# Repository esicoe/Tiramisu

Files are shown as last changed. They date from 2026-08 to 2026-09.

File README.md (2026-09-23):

# Tiramisu: a 1000 Hz Hall-effect osu! tablet

<p align="center">
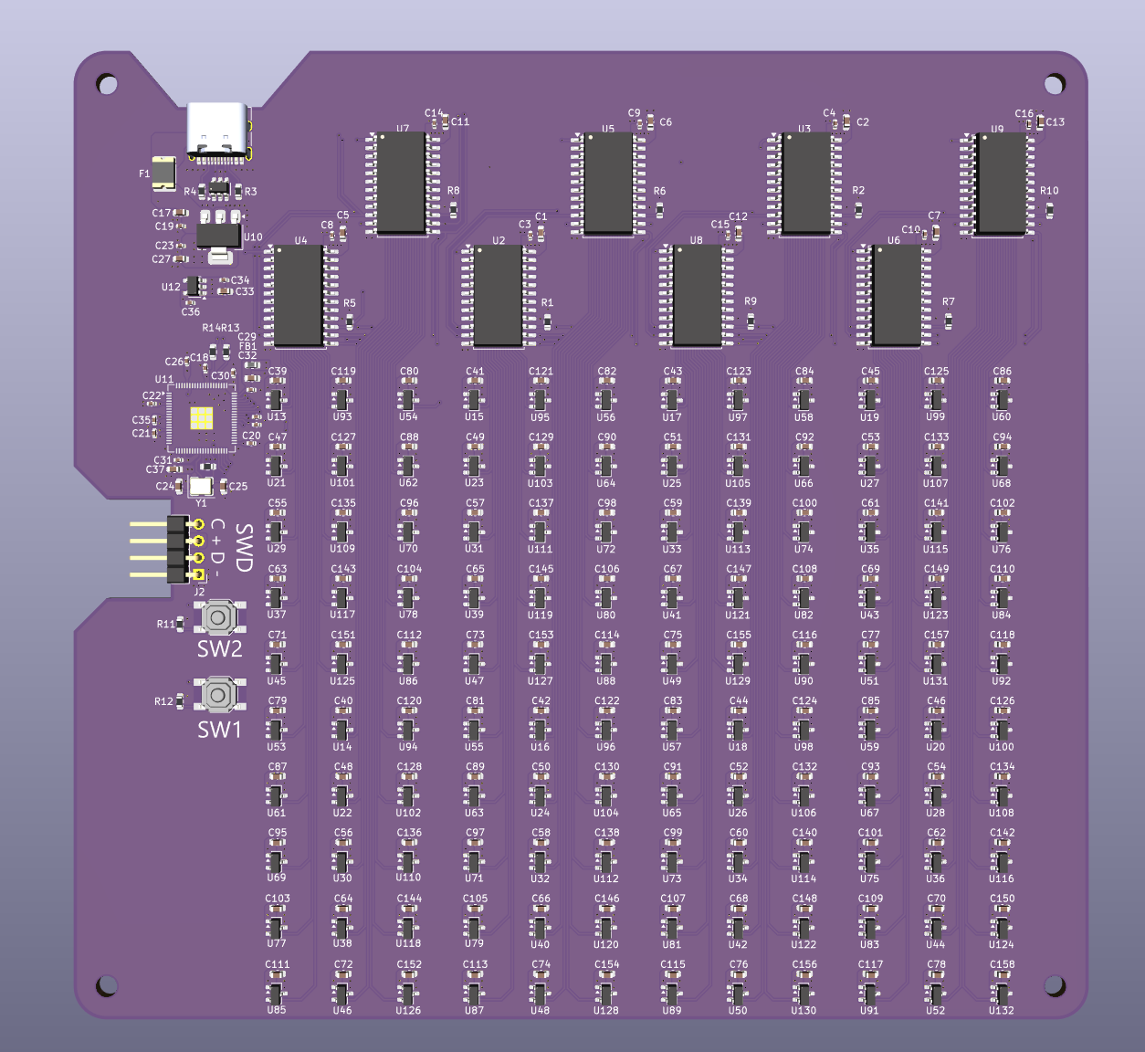
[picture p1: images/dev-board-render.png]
KiCad render of the aim1k dev board
  
</p>

Tiramisu is a drawing tablet for [osu!](https://osu.ppy.sh) that tracks a magnet-tipped pen with a grid of
120 Hall-effect sensors and reports its position over USB **1000 times a second**. That's the USB Full-Speed
ceiling, and 7.5x the 133 Hz of a Wacom CTL-472.

It's my independent prototype of the Hall-effect tablet we're building at
[Wonkle](https://github.com/wonkleio). The board and firmware go by **aim1k** in the source.

## Status

| Board | State |
|---|---|
| `tiramisu-dev-RP2354B` | Fabricated and assembled by JLCPCB, brought up, tracking a magnetic pen |
| `tiramisu-dev-CH32V307` | Next revision, in part selection: a RISC-V MCU with built-in USB 2.0 High-Speed to go past 1 kHz |

## Hardware: `tiramisu-dev-RP2354B`

| | |
|---|---|
| MCU | Raspberry Pi RP2354B (dual Arm Cortex-M33, 2 MB in-package flash) |
| Sensors | 120 x HAL403 linear Hall sensors in a 12 x 10 grid at 10 mm pitch |
| Multiplexing | 8 x CD74HC4067 16:1 analog muxes on a shared select bus, one per ADC input |
| PCB | 4 layers, 154 x 147 mm, designed in KiCad |
| Interface | USB-C (Full-Speed): HID plus an optional CDC debug console. SWD header for debugging |

## How it works

- **Scan (core 1).** DMA-driven round-robin over all 120 sensors at about 1.8 kHz per full frame, keeping a
  baseline and a noise sigma for every sensor. A warm-up conversion pass removes the crosstalk that the
  multiplexers' on-resistance causes in the ADC's sample-and-hold.
- **Solve (core 0).** Detects the pen from per-sensor noise thresholds and spatial coherence, seeds a position
  from the centroid, then refines x, y and hover height with a Levenberg-Marquardt fit of a magnetic dipole. A
  1-Euro filter smooths the output without adding lag during fast flicks.
- **Report.** 1 kHz USB HID, paced by the host's polling. The device exposes two collections: an absolute mouse
  that works with no driver, and a vendor-defined collection for [OpenTabletDriver](https://opentabletdriver.net).

The [firmware README](tiramisu-dev-RP2354B/firmware/README.md) covers the solver, the tuning decisions and how
to test without hardware. The [sensing calculations](tiramisu-dev-RP2354B/docs/CALCULATIONS.md) cover grid
geometry, scan-rate budget and magnet choice.

## Repository layout

```
tiramisu-dev-RP2354B/
  pcb/               KiCad project: schematic and 4-layer layout
  manufacturing/     Gerbers, BOM and pick-and-place files for JLCPCB
  firmware/          C firmware on the Pico SDK and TinyUSB
  scripts/           Python host tools
  opentabletdriver/  OpenTabletDriver tablet config and report parser
  docs/              Sensing and scan-rate calculations
  datasheets/
tiramisu-dev-CH32V307/   Next revision (datasheets so far)
images/                  Photos and renders for this README
```

## Build and flash

The build uses the Raspberry Pi Pico SDK. The Pico VS Code extension installs the SDK, the Arm toolchain, CMake
and Ninja in one go.

```powershell
cd tiramisu-dev-RP2354B/firmware
.\build.ps1           # configure (first time) and build
.\build.ps1 -Clean    # wipe build/ and reconfigure
```

Hold **BOOTSEL**, plug the board in, and copy `build/aim1k.uf2` onto the drive that appears.

## Host tools

All of these are Python 3 with no third-party packages. The USB tools use Windows APIs.

| Script | What it does |
|---|---|
| `scripts/grid_view.py` | Live heatmap of the sensor grid over the debug console, plus noise, raw, baseline and recalibrate views |
| `scripts/rate_test.py` | Measures the real HID report rate and its jitter at the host |
| `scripts/set_mode.py` | Turns the driverless mouse collection on or off |
| `scripts/gen_sensor_map.py` | Regenerates the firmware's sensor map straight from the KiCad PCB |

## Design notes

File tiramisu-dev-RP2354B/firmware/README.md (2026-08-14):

# aim1k tablet firmware

RP2354B firmware that scans the 120-sensor HAL403 grid, localises the pen magnet,
and reports absolute position over USB through two HID collections — an absolute
mouse (driverless cursor, no Windows Ink) and a vendor-defined one for
OpenTabletDriver. Deliberately NOT a Digitizer/Pen device; see config.h for why.

## Layout

```
include/config.h        build-time config (USB IDs, area, rates, DSP knobs)
include/sensor_map.h    AUTO-GENERATED (mux/channel -> grid) from the KiCad PCB
include/hid_report.h    the 7-byte pen report struct
src/sensors.[ch]        core-1 DMA round-robin scan -> 120 deflections (seqlock),
                        per-sensor baseline + noise sigma (Welford)
src/solve.[ch]          presence (sigma + spatial coherence + hysteresis) and
                        localisation (centroid seed -> LM dipole fit)
src/filter.[ch]         1-Euro adaptive output filter
src/usb_descriptors.c   mouse + vendor collections, optional CDC console,
                        TinyUSB glue
src/tusb_config.h       TinyUSB config
src/main.c              core-0: USB + solve + filter + 1 kHz report loop
../scripts/grid_view.py host-side live heatmap over the CDC console
```

## Debug console

`DEBUG_CONSOLE 1` (default) adds a USB CDC serial port alongside the HID
interface. It is how the sensor map and the noise thresholds get verified:

```bash
python ../scripts/grid_view.py        # live heatmap
```

Touch the magnet to one physical sensor and confirm the lit cell appears at the
matching (col,row). If it lights elsewhere, that entry in `SENSOR_GRID` is wrong
and the heatmap shows where it actually landed. `noise`, `raw`, `baseline`, and
`cal` are the other subcommands. Set `DEBUG_CONSOLE 0` for a release build to
drop the CDC interface entirely.

Over a raw serial terminal the console also takes single keys — `i` for a status
line and `j` for a jitter measurement:

```
i    scan 1812 Hz | sigma min 0.75 mean 1.31 max 2.04 counts | solve 61 us avg 88 us max (budget 1000)
     pen IN  peak 197.4 snr 96.8 coh 0.11  x 59.51 y 40.02 z 10.3 (dipole) rms 1.9
```

The four numbers to read when something is wrong:

- **`solve ... us`** against the 1000 µs budget. The report loop runs at 1 kHz;
  if the average approaches that, the fit is not finishing in its slot.
- **`rms` against `peak`.** This is the dipole fit's residual — how well a real
  magnet is described by the model. It should be a few percent of `peak`. If it
  sits near `FIT_MAX_RESID_FRAC` (0.25) with the pen plainly on the tablet, the
  fit-quality gate is rejecting good frames and that constant needs raising.
- **`coh`.** Spatial coherence, which falls as the pen gets *closer* (see the
  table in `config.h`). Under `COHERENCE_MIN` the pen is not detected at all.
- **`z`.** Fitted hover height. Over `HOVER_MAX_Z_MM` the pen drops out.

`j` parks a 2-second capture and reports the standard deviation and
peak-to-peak of the reported position, before and after the output filter:

```
j    jitter over 2000 frames (mm)
       solver   sd 0.1103 0.1147  p2p 0.612 0.658
       filtered sd 0.0129 0.0134  p2p 0.083 0.094
```

Hold the pen still and read the **filtered p2p** — that is how far the cursor
wanders on its own. A large p2p next to a small sd means isolated glitches
rather than noise, which is the one case `MEDIAN_TAPS 3` is for.

## Build

```powershell
.\build.ps1            # configure (first time) + build
.\build.ps1 -Clean     # wipe build/ and reconfigure
```

`build.ps1` finds the toolchain in either place one ends up: a standalone
`C:\pico` layout, or `%USERPROFILE%\.pico-sdk\` — which is what the Raspberry Pi
Pico VS Code extension installs, and which brings its own SDK, arm-none-eabi,
CMake, Ninja and picotool. It picks the newest version of each.

Output is `build/aim1k.uf2`. To flash: hold **BOOTSEL**, plug in the RP2354B,
copy `aim1k.uf2` onto the drive that appears.

Current build: **46 KB flash, 15 KB RAM** — trivially fits the RP2354B's 2 MB /
520 KB. (Most of that is the SDK 2.3.0 / GCC 15 toolchain rather than this code;
the same source was 20.7 KB under SDK 2.1.1 / GCC 13.)

Building the firmware is not the only way to work on the solver — see *Testing
the solver without hardware* below.

## Why the cursor holds still

A 10 mm sensor pitch means the position between sensors is *interpolated*, so
every discrete decision the solver makes is a chance to turn a stationary magnet
into a moving cursor. Five things exist purely to stop that, in rough order of
how much they matter (all measured against synthetic frames — peak 200 counts,
sigma 2, magnet at 8 mm — with the harness described below):

1. **Priors on the fit's nuisance parameters** (`FIT_NUISANCE_PRIOR`). Magnet
   strength `A` and hover height `z` cannot change at 1 kHz, but the fit
   re-derived them every frame, and because the model's parameters are
   correlated their noise came back out as *position* noise. Tying them to the
   previous frame while leaving x/y completely free: 0.131 → 0.058 mm rms with
   `z` pinned outright, 0.111 mm with the adaptive prior actually shipped. No
   latency cost, because position is never constrained.
2. **Coherence threshold** (`COHERENCE_MIN`, 0.18 → **−0.10**). This one took two
   goes to get right, and the reason is worth stating plainly: **coherence is a
   monotonically decreasing function of how close the pen is**, because the
   peak's neighbours 10 mm away sit in the dipole's *negative skirt*. So any
   positive threshold is a minimum hover height in disguise — press the pen down
   harder and the tablet cuts out. At 0.18 the pen did not exist below ~10 mm.
   Lowering it to 0.05 moved the wall rather than removing it: a left-edge drag
   measured 100% usable at 7 mm, 99.8% at 6 mm, and **79% at 5 mm with presence
   chattering 213 times in four seconds** — every failure the coherence test,
   with amplitude, residual, height and area never firing. Only a negative floor
   removes the wall entirely. It now sits below what a magnet produces at ~3 mm,
   which is below anything a 10 mm pitch can localise anyway.
3. **Baseline time constant** (`BASELINE_ALPHA`, 0.0005 → 3.0e-5) and freezing
   it while a pen is present. At ~1.8 kHz the old value was a 1.1 *second* time
   constant sitting directly under the pen: rest the magnet anywhere and the
   baseline crawled up to meet it, eating the blob's skirt first and deforming
   the shape the solver was fitting.
4. **Peak-cell hysteresis** (`PEAK_HOLD_MARGIN_SIGMA`). The analysis window
   hangs off the argmax; a magnet parked between two sensors let noise re-decide
   that every frame, sliding the window a full pitch each time.
5. **Frame-count debounce** on presence, so a marginal frame costs nothing
   instead of a filter reset and a cursor jump.

End to end, worst position found by sweeping the magnet over a 10 × 10 mm cell
at 0.5 mm steps, cursor peak-to-peak with the output filter in place:

| hover | before | after |
|---|---|---|
| 8 mm  | 0.54 mm | 0.25 mm |
| 12 mm | 1.02 mm | 0.51 mm |

Latency is unchanged: 0.88 ms at 400 mm/s (was 0.87), 3.81 ms at 40 mm/s (was
4.13, i.e. slightly better).

## Out of range

`solve_position` reports `in_range` false — and `main.c` then stops sending
reports entirely, freeing the cursor — when any of these hold for
`PRESENCE_EXIT_FRAMES` consecutive frames:

- **the peak has collapsed to under `PRESENCE_RELEASE_FRAC` of what this contact
  has been reading.** This is the test that actually releases the pen, and it is
  relative because no absolute one can work: the threshold has to sit low enough
  for the weakest pen worth seeing, and a strong magnet reading 865 counts would
  have to travel nearly 4x further away before it fell through
  `PRESENCE_EXIT_SNR * sigma` ≈ 16 counts. The reference is a symmetric average
  over `PEAK_REF_TAU_S`, so any hover height held for longer than that simply
  becomes the new reference and only a change faster than it — lifting the pen —
  trips the test;
- peak below `PRESENCE_EXIT_SNR` sigma, or coherence below `COHERENCE_EXIT_MIN`
  (pen gone, or a single drifted sensor pretending to be one);
- fitted `z` over `HOVER_MAX_Z_MM` (pen held too high to localise);
- fit residual over the `FIT_MAX_RESID_*` gate (whatever is on the grid is not
  a magnet on the surface);
- the fit places the pen more than `AREA_MARGIN_MM` outside the sensor-centre
  span (**pen off the edge of the tablet**).

That last one is only possible because the fit's x/y are unconstrained: push the
magnet past the last column and the peak cell stays pinned to that column, but
the fit — which knows what the field's shape should look like — reports a
position out beyond the edge. A centroid cannot do this; it is trapped inside
the grid, which is why a centroid-only tablet smears and jitters along its
border instead of admitting the pen has left.

### The phantom pen

A phantom is a POSITIVE blob on the grid with no magnet present, and there is
exactly one way to make one: the baseline learned a value that is too LOW,
which means it was learned while a NEGATIVE field sat on the tablet. A negative
field is the magnet's other pole — the pen resting flipped, or lying on its
side, which is the natural way to put a pen down. Presence only searches for
positive peaks, so a negative field is invisible to it, and any ungated "no pen
detected, track freely" baseline rate will absorb it wholesale. Pick the pen up
and its positive mirror image stands up out of the corrected-for field: full
pen amplitude, dipole-shaped to within noise (it IS the pen's field, frozen),
fitting a plausible hover height. It passes every test the solver has, because
it is a perfect recording of something that passed every test. One was captured
on hardware holding peak ~900 / z 12.0, motionless, for five unbroken minutes.

Weak phantoms exist too (drift accumulated under a long-parked pen, the
positive ring around the hole left by calibrating with the magnet on), but the
full-amplitude image is the one that cannot be beaten after the fact: a real
pen between sensors reads LESS than the image does, so no amplitude contest,
threshold, or release rule can prefer the pen once the image exists. The only
winning move is to make images impossible to create. Defences, in order:

1. `BASELINE_GATE_SNR` — no baseline rate may follow a deflection beyond a few
   sigma, in either polarity. Drift creeps, so a tracking baseline never
   legitimately sees more; anything bigger is a field, and fields are never
   absorbed. This kills the formation path outright.
2. The post-release re-zero pass (`BASELINE_ALPHA_REZERO`) is the single
   exception, and it is ungated for POSITIVE deflections only — its targets
   (leftover images, drift from under a parked pen) are positive, and
   absorbing a large negative deflection is precisely the act of minting a
   phantom.
3. `PRESENCE_REACQUIRE_BLOCK_MS` — after a release, nothing may be acquired,
   flat, no exceptions, while the re-zero runs. An image is at full pen
   amplitude, so any exception lenient enough to admit a returning pen admits
   the image, which then freezes its own neighbourhood and cancels the erase.
4. The peak tracker never walks to a FAR rival while its own cell's signal has
   collapsed. One magnet cannot jump several pitches in a millisecond, so that
   situation is always "the pen left while a second source exists" — hold the
   dying cell, release, and let the re-zero deal with whatever the rival is.
   This is both how weak phantoms get erased by ordinary use (one contact and
   lift heals them) and why the cursor no longer teleports onto a second blob
   whenever the pen lifts.

What remains: a full image can still be BAKED IN by booting — the calibration
runs ~0.5 s after power-up and trusts whatever it sees — with a magnet resting
on (or flipped on) the tablet. Nothing at runtime can distinguish that from a
clean zero, so keep the tablet clear when plugging in; `c` on the console
re-zeros and fixes it immediately if it happens.

## Testing the solver without hardware

`solve.c` and `filter.c` have no SDK dependencies beyond `sensor_map.h`, so they
compile natively against a synthetic grid. The magnet is modelled as a pair of
magnetic charges (a finite cylinder), *not* as the point dipole the solver fits,
so the fit sees real model mismatch; per-sensor gain spread is included for the
same reason. Stub `sensors_sigma()` and friends, generate frames, and measure.
This is how every number above was obtained, and it is much faster than
guessing at a tablet.

## Bring-up order (do these on a scope/logic analyser first)

1. **Confirm HAL403SO is the linear/ratiometric part** (analog output). The ADC
   path is meaningless for a switch-type Hall. See `../datasheets/HAL403.pdf`.
2. **Select-line sanity.** Toggle S0..S3 (GPIO32/31/30/29) and verify each mux
   walks channels 0..14. `sensor_map.h` assumes address = channel index.
3. **Settle time.** `sensors.c: set_address()` waits 5 µs. Scope one COM line
   after an address change and shrink/grow this until it is just clean at 12-bit.
4. **Baseline + polarity.** With no pen, `sensors_calibrate_baseline()` should
   leave deflections near zero. Bring the magnet down over one sensor and confirm
   the deflection goes **positive** (the code weights on positive deflection). If
   it goes negative, flip the magnet, or negate in `raw_frame()`.
5. **Grid orientation.** Move the pen right/down and confirm reported X/Y move the
   right way. Add axis flips in `main.c: send_pen()` if the board is mounted
   rotated/mirrored.

## Known stubs / next steps

- **Clicks are keyboard-only, by design.** The tablet is hover-only: it reports
  position and never asserts a tip switch. Bind osu! K1/K2 on the keyboard as
  usual. Pressure stays 0.
- **DMA round-robin on core 1** is done: core 1 scans the grid (DMA drains the 8
  ADC inputs per address) and publishes frames through a seqlock; core 0 only
  runs USB + solve. Core-1 frame rate is ~1.4 kHz (2x oversampled), independent
  of the 1 kHz report loop, with headroom to push higher (drop OVERSAMPLE or
  trim the 5 us settle in `sensors.c`).
- **Dipole refine** in `solve.c` is implemented (Levenberg-Marquardt over the
  5x5 window, falling back to the centroid if it fails to converge or wanders
  outside the window). It removes the centroid's edge bias and its bias from the
  field's negative skirt.
- Regenerate `sensor_map.h` whenever the PCB changes:
  `python ../scripts/gen_sensor_map.py --write`. It reads placements, net
  connectivity, and pin functions out of `pcb/tiramisu-dev.kicad_pcb`, so it never
  assumes a pinout — which matters, because the CD74HC4067 footprint here does
  not use the pad order the datasheet would suggest (pad 1 is COM, not I5), and
  the ADC net names are reversed relative to the ADC input numbers.
- Confirm the map on hardware with `../scripts/grid_view.py` after regenerating.

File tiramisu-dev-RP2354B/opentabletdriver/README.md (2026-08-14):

# aim1k — OpenTabletDriver support

Two files:

- `aim1k.json` — the tablet configuration (VID/PID, physical size, report parser).
- `Aim1kReportParser.cs` — decodes the 8-byte HID report into an OTD report.

## Why both

The firmware exposes a **vendor-defined HID collection** alongside the
absolute-mouse one (see `HID personality` in `../firmware/include/config.h`).
That is deliberate, and it is what makes OTD work at all:

- Windows opens **Digitizer/Pen** collections **exclusively**. With a pen
  descriptor, OTD — or any other userspace reader — gets `ACCESS_DENIED` when it
  tries to open the device. No OTD config can work around that.
- A pen descriptor also puts **Windows Ink** in the path, which is exactly the
  smoothing and press-and-hold behaviour osu! players turn off.

A vendor-defined collection sidesteps both. On its own it would mean nothing
moves the cursor without OTD, which is why the firmware also ships the
absolute-mouse collection beside it: Windows claims collections individually, so
the mouse drives the cursor driverless while the vendor one stays open for OTD.
OTD switches the mouse off when it connects (`FeatureInitReport` below) so the
two never fight. Set `VENDOR_ONLY 1` in `config.h` to drop the mouse collection
entirely, or `MOUSE_DEFAULT_ON 0` to leave it silent until something asks.

## Install

**No plugin DLL is needed.** `Aim1kReportParser.cs` is kept only as a starting
point if you later want proximity or pressure handling; the stock parser covers
the current report exactly.

1. Copy `aim1k.json` into the OTD configurations folder:
   - Windows: `%LOCALAPPDATA%\OpenTabletDriver\Configurations\`

   Creating that folder is safe: OTD **adds** these to its built-in configs
   rather than replacing them (verified on 0.6.7 — 341 configs loaded, all the
   stock ones still present alongside aim1k).

2. **Restart the OTD daemon.** This step is not optional and is the most likely
   thing to waste your time: the daemon enumerates HID devices once at startup,
   so a daemon that was already running when you reflashed the firmware will
   report `Device not found` even though the config loads and the device is
   plainly visible to everything else. Kill `OpenTabletDriver.Daemon.exe` and
   start it again after any reflash that changes the USB descriptors.

3. The tablet appears as **"aim1k tablet"**, 110 × 90 mm. Map your osu! area
   inside that with output mode *Absolute*.

A healthy detection looks like this in the log
(`%LOCALAPPDATA%\OpenTabletDriver\Logs\`):

```
[Device] Initializing device 'aim1k tablet' \\?\hid#vid_1209&pid_0001&mi_02&col02#...
[Device] Using report parser type 'OpenTabletDriver.Plugin.Tablet.TabletReportParser'
[Device] Set device feature: 03-00
[Detect] Found tablet 'aim1k tablet'
```

`col02` confirms it bound to the vendor collection rather than the mouse one, and
`Set device feature: 03-00` is `FeatureInitReport` switching the absolute-mouse
collection off so OTD alone drives the cursor.

## Notes

- `MaxX/Width = 100`, i.e. coordinates are in 0.01 mm — matches the firmware.
- Pressure is currently synthesised from the tip-switch bit (0 or full scale), so
  OTD's pressure-based tip binding works once you wire a tip switch. Until then
  the tablet is hover-only; bind clicks to the keyboard as usual for osu!.
- If OTD does not pick it up, double-check the VID/PID in `aim1k.json` matches
  `USB_VID`/`USB_PID` in `../firmware/include/config.h`.

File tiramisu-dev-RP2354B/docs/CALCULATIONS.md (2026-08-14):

# aim1k tablet — sensing calculations

All numbers below are derived from the KiCad files in `pcb/`
(120 × HAL403SO, RP2354B, 8 × CD74HC4067). Re-run the extraction in
`scripts/gen_sensor_map.py` if the board changes.

## 1. Grid geometry (measured from the PCB)

| Quantity | Value |
|---|---|
| Sensors | **120** (HAL403SO, SOT-23) |
| Layout | **12 columns × 10 rows** |
| Pitch | **10.0 mm** in X and Y |
| Sensor-centre span | **110 mm × 90 mm** (col 0→11, row 0→9) |
| Aspect ratio | 110:90 = 1.22 (osu! playfield is 4:3 = 1.33 — crop in software) |

**Usable active area.** A magnet is localised by interpolating between the
sensors that surround it. Near the outer edge the magnet is only "seen" from one
side, so accuracy degrades within ~½ pitch of the border. Plan for a reliable
interior of about **100 mm × 80 mm**, and let OpenTabletDriver map a smaller
osu! area inside that.

## 2. Electrical / scan architecture (from the schematic)

- **Select lines S0–S3 are a shared bus** → `S0=GPIO32, S1=GPIO31, S2=GPIO30, S3=GPIO29`.
- **Mux enables (E) are tied low in hardware** (10 kΩ to GND, not on the MCU),
  so **all 8 muxes are always enabled** and present their selected channel
  simultaneously.
- **8 mux COM outputs → the RP2350 ADC pins**, but the net names are **reversed**:
  net `ADC0` (mux A) is on **GPIO47 = ADC input 7**, … net `ADC7` (mux H) is on
  **GPIO40 = ADC input 0**. Encoded as `MUX_ADC_INPUT[A..H] = {7,6,5,4,3,2,1,0}`.
- **Each mux drives 15 sensors** (channels 0–14); **channel 15 is unused** on all
  eight. So a full frame is **15 select addresses × 8 muxes = 120 reads**.

The RP2350 has **one** ADC behind an 8-input front mux, so the 8 mux COMs are read
*round-robin*, not truly in parallel.

## 3. Scan-rate budget

Per select address: set 4 GPIOs, wait for the analog line to settle, then convert
8 channels round-robin.

| Item | Time |
|---|---|
| RP2350 ADC conversion | ~2.0 µs / sample (500 kSa/s) |
| 8 channels / address | ~16 µs |
| Mux + line settle (conservative) | ~5 µs |
| **Per address** | **~21 µs** |
| **15 addresses = full 120-sensor frame** | **~315 µs → ~3.2 kHz** |

Even at a pessimistic 2× overhead you clear **1.5 kHz full-grid**, so:

- **1000 Hz USB report rate is comfortably met** (USB Full-Speed, 1 ms interval).
- There is headroom to **oversample** (average 2–3 frames) to cut noise ~1.4–1.7×
  and still report at 1 kHz.
- Free-run the scan on **core 1** (DMA-fed round-robin), solve position on **core 0**.

## 4. Magnet & working height (this changes your earlier plan)

Pen magnet: **6 mm ⌀ × 10 mm** axially-magnetised NdFeB cylinder (N42≈Br 1.32 T).
On-axis field of a cylinder at distance `z` from the pole face:

```
B(z) = (Br/2) · [ (L+z)/√(R²+(L+z)²) − z/√(R²+z²) ],   R=3 mm, L=10 mm
```

| z (magnet face → sensor plane) | B |
|---|---|
| 5 mm | ~81 mT |
| 8 mm | ~33 mT |
| **10 mm** | **~21 mT** |
| 12 mm | ~14 mT |
| 15 mm | ~8 mT |
| 17 mm | ~6 mT |

**Key correction.** Earlier I said "get the magnet as close to the tip as
possible." That is right for a *single* sensor, but **wrong for a 10 mm-pitch
array.** If the magnet is 2–3 mm away the field is a sharp spike over essentially
one sensor and you **cannot interpolate** where between sensors it sits. For an
array the field "spot" at the sensor plane should span ~2–3 pitches, i.e. the
**working height should be ≈ the pitch, ~8–12 mm.**

So the target is:

```
working height  =  (tip-to-magnet-face gap)  +  (cover thickness)  ≈  8–12 mm
```

With a ~1.5–2 mm cover sheet, the **magnet face should sit ~6–10 mm behind the
pen-tip contact point** — not 2–5 mm, and not 15 mm.

- **Your current 15 mm** puts the magnet ~17 mm from the sensors → only ~6 mT and
  a broad, low-amplitude peak. Workable but noise-limited; pull it forward.
- **Sweet spot ≈ 8 mm behind the tip** → ~10 mm working height, ~21 mT, peak
  spread across a 3×3 neighbourhood. That is the number to build to.

## 5. Expected resolution

- Raw pitch is 10 mm, but with weighted-centroid / dipole interpolation over a
  3×3–5×5 neighbourhood and a 12-bit ADC, position resolution of **~0.05–0.2 mm**
  is realistic when SNR is good (another reason to favour ~21 mT over ~6 mT).
- Mapped to a 1920 px width over a ~100 mm area (~0.05 mm/px), that is roughly
  one-screen-pixel precision — adequate for osu!, **noise-limited, not
  pitch-limited**, which is why working height and calibration matter most.

## 6. Open hardware questions to confirm

1. **Is HAL403SO the linear/ratiometric Hall (analog output), not a switch?**
   The ADC readout only works with an analog-output part. Confirm against
   `datasheets/HAL403.pdf`.
2. **Pen click / tip switch.** A rigid magnet-in-pen gives *hover only*. osu!
   players usually click with the keyboard, so hover + keyboard is fine, but if
   you want a pen "tap = click" you need either a tip micro-switch (add a GPIO) or
   a z-threshold gesture. The firmware exposes a `tip_switch` bit that is
   currently stubbed off — wire it to whichever you choose.

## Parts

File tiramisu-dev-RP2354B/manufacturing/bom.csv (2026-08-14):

Designator | Footprint | Quantity | Value | LCSC Part #
C1, C11, C12, C13, C2, C33, C5, C6, C7 | 0603 | 9 | 1u | C15849
C10, C14, C15, C16, C18, C19, C20, C21, C22, C23, C26, C28, C3, C30, C31, C32, C34, C35, C36, C38, C4, C8, C9 | 0402 | 23 | 100n | C1525
C100, C101, C102, C103, C104, C105, C106, C107, C108, C109, C110, C111, C112, C113, C114, C115, C116, C117, C118, C119, C120, C121, C122, C123, C124, C125, C126, C127, C128, C129, C130, C131, C132, C133, C134, C135, C136, C137, C138, C139, C140, C141, C142, C143, C144, C145, C146, C147, C148, C149, C150, C151, C152, C153, C154, C155, C156, C157, C158, C39, C40, C41, C42, C43, C44, C45, C46, C47, C48, C49, C50, C51, C52, C53, C54, C55, C56, C57, C58, C59, C60, C61, C62, C63, C64, C65, C66, C67, C68, C69, C70, C71, C72, C73, C74, C75, C76, C77, C78, C79, C80, C81, C82, C83, C84, C85, C86, C87, C88, C89, C90, C91, C92, C93, C94, C95, C96, C97, C98, C99 | 0603 | 120 | 0.1u | C14663
C17 | 0603 | 1 | 10u | C96446
C24, C25 | 0603 | 2 | 15p | C1644
C27 | 0603 | 1 | 22u | C59461
C29, C37 | 0603 | 2 | 4u7 | C19666
F1 | 1812 | 1 | SMD1812P075TF/24 | C12557
FB1 | 0603 | 1 | GZ1608D601TF | C1002
J1 | USB_C_Receptacle_HRO_TYPE-C-31-M-12 | 1 | TYPE-C-31-M-12 | C165948
R1, R10, R2, R5, R6, R7, R8, R9 | 0603 | 8 | 10K | C25804
R11, R12, R15 | 0603 | 3 | 1K | C21190
R13, R14 | 0603 | 2 | 27R | C25190
R3, R4 | 0603 | 2 | 5.1K | C23186
SW1, SW2 | SW_SPST_SKQG_WithStem | 2 | TS-1187A-B-A-B | C318884
U1 | SOT-23-6 | 1 | SRV05-4 | C85364
U10 | SOT-223-3_TabPin2 | 1 | AMS1117-3.3 | C6186
U100, U101, U102, U103, U104, U105, U106, U107, U108, U109, U110, U111, U112, U113, U114, U115, U116, U117, U118, U119, U120, U121, U122, U123, U124, U125, U126, U127, U128, U129, U13, U130, U131, U132, U14, U15, U16, U17, U18, U19, U20, U21, U22, U23, U24, U25, U26, U27, U28, U29, U30, U31, U32, U33, U34, U35, U36, U37, U38, U39, U40, U41, U42, U43, U44, U45, U46, U47, U48, U49, U50, U51, U52, U53, U54, U55, U56, U57, U58, U59, U60, U61, U62, U63, U64, U65, U66, U67, U68, U69, U70, U71, U72, U73, U74, U75, U76, U77, U78, U79, U80, U81, U82, U83, U84, U85, U86, U87, U88, U89, U90, U91, U92, U93, U94, U95, U96, U97, U98, U99 | SOT-23 | 120 | HAL403SO | C42387470
U11 | QFN-80-1EP_10x10mm_P0.4mm_EP3.4x3.4mm | 1 | RP2354B | C39843328
U12 | SOT-23-5 | 1 | TLV73311PDBV | C2865431
U2, U3, U4, U5, U6, U7, U8, U9 | SOIC-24W_7.5x15.4mm_P1.27mm | 8 | CD74HC4067M | C496123
Y1 | Crystal_SMD_3225-4Pin_3.2x2.5mm | 1 | ABM8-272-T3 | C20625731

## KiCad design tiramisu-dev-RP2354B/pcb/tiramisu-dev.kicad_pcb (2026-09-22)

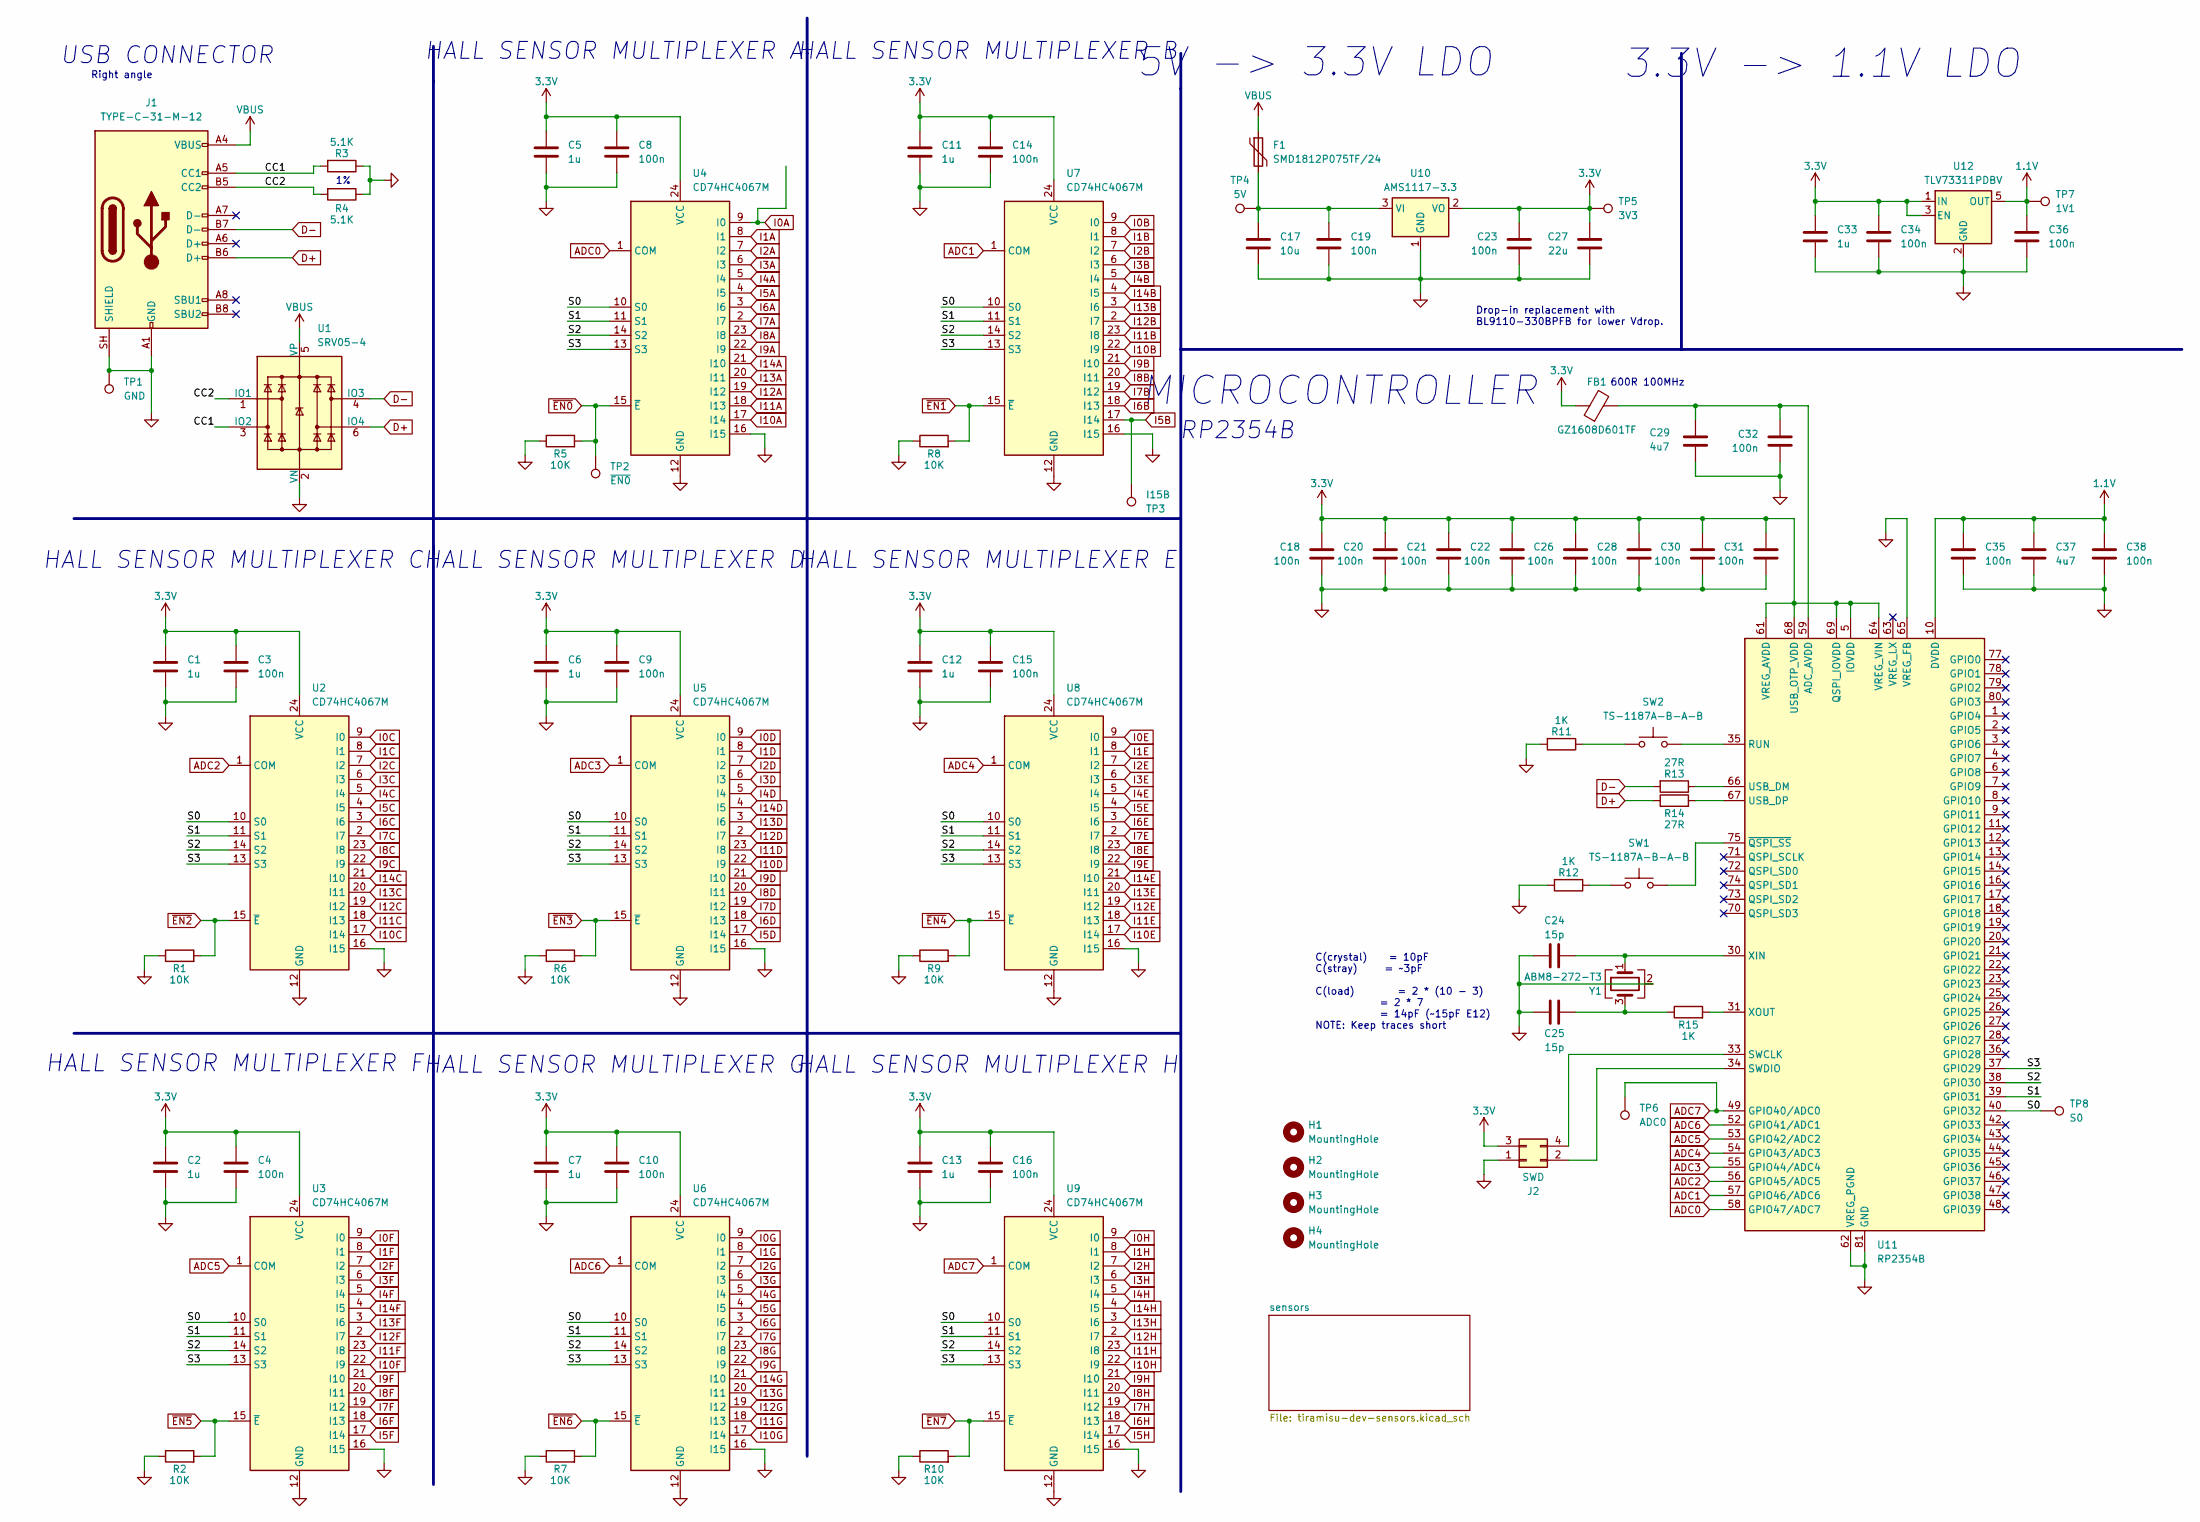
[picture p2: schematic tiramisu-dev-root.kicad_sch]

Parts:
C1, C2, C5, C6, C7, C11, C12, C13, C33: 1u; C_0603_1608Metric
C3, C4, C8, C9, C10, C14, C15, C16, C18, C19, C20, C21, C22, C23, C26, C28, C30, C31, C32, C34, C35, C36, C38: 100n; C_0402_1005Metric
C17: 10u; C_0603_1608Metric
C24, C25: 15p; C_0603_1608Metric
C27: 22u; C_0603_1608Metric
C29, C37: 4u7; C_0603_1608Metric
F1: SMD1812P075TF/24; Fuse_1812_4532Metric
FB1: GZ1608D601TF; L_0603_1608Metric
H1, H2, H3, H4: MountingHole; MountingHole_3.2mm_M3
J1: TYPE-C-31-M-12; USB_C_Receptacle_HRO_TYPE-C-31-M-12
J2: SWD; PinHeader_1x04_P2.54mm_Horizontal
R1, R2, R5, R6, R7, R8, R9, R10: 10K; R_0603_1608Metric
R3, R4: 5.1K; R_0603_1608Metric
R11, R12, R15: 1K; R_0603_1608Metric
R13, R14: 27R; R_0603_1608Metric
SW1, SW2: TS-1187A-B-A-B; SW_SPST_SKQG_WithStem
TP1: GND; TestPoint_Pad_D4.0mm
TP2: ~{EN0}; TestPoint_Pad_D4.0mm
TP3: I15B; TestPoint_Pad_D4.0mm
TP4: 5V; TestPoint_Pad_D4.0mm
TP5: 3V3; TestPoint_Pad_D4.0mm
TP6: ADC0; TestPoint_Pad_D4.0mm
TP7: 1V1; TestPoint_Pad_D4.0mm
TP8: S0; TestPoint_Pad_D4.0mm
U1: SRV05-4; SOT-23-6
U2, U3, U4, U5, U6, U7, U8, U9: CD74HC4067M; SOIC-24W_7.5x15.4mm_P1.27mm
U10: AMS1117-3.3; SOT-223-3_TabPin2
U11: RP2354B; QFN-80-1EP_10x10mm_P0.4mm_EP3.4x3.4mm
U12: TLV73311PDBV; SOT-23-5
Y1: ABM8-272-T3; Crystal_SMD_3225-4Pin_3.2x2.5mm

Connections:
1.1V: C35.1, C36.1, C37.1, C38.1, TP7.1 (1_1), U11.10 (DVDD), U11.32 (DVDD), U11.51 (DVDD), U12.5 (OUT)
3.3V: C1.1, C2.1, C3.1, C4.1, C5.1, C6.1, C7.1, C8.1, C9.1, C10.1, C11.1, C12.1, C13.1, C14.1, C15.1, C16.1, C18.1, C20.1, C21.1, C22.1, C23.1, C26.1, C27.1, C28.1, C30.1, C31.1, C33.1, C34.1, FB1.1, J2.3, TP5.1 (1_1), U2.24 (VCC), U3.24 (VCC), U4.24 (VCC), U5.24 (VCC), U6.24 (VCC), U7.24 (VCC), U8.24 (VCC), U9.24 (VCC), U10.2 (VO), U11.5 (IOVDD), U11.15 (IOVDD), U11.24 (IOVDD), U11.29 (IOVDD), U11.41 (IOVDD), U11.50 (IOVDD), U11.60 (IOVDD), U11.61 (VREG_AVDD), U11.64 (VREG_VIN), U11.68 (USB_OTP_VDD), U11.69 (QSPI_IOVDD), U11.76 (IOVDD), U12.1 (IN), U12.3 (EN); also elsewhere on the board
/CC1: J1.A5 (CC1), R3.2, U1.3 (IO2)
/CC2: J1.B5 (CC2), R4.2, U1.1 (IO1)
/S0: TP8.1 (1_1), U2.10 (S0), U3.10 (S0), U4.10 (S0), U5.10 (S0), U6.10 (S0), U7.10 (S0), U8.10 (S0), U9.10 (S0), U11.40 (GPIO32)
/S1: U2.11 (S1), U3.11 (S1), U4.11 (S1), U5.11 (S1), U6.11 (S1), U7.11 (S1), U8.11 (S1), U9.11 (S1), U11.39 (GPIO31)
/S2: U2.14 (S2), U3.14 (S2), U4.14 (S2), U5.14 (S2), U6.14 (S2), U7.14 (S2), U8.14 (S2), U9.14 (S2), U11.38 (GPIO30)
/S3: U2.13 (S3), U3.13 (S3), U4.13 (S3), U5.13 (S3), U6.13 (S3), U7.13 (S3), U8.13 (S3), U9.13 (S3), U11.37 (GPIO29)
ADC0: U4.1 (COM), U11.58 (GPIO47/ADC7)
ADC1: U7.1 (COM), U11.57 (GPIO46/ADC6)
ADC2: U2.1 (COM), U11.56 (GPIO45/ADC5)
ADC3: U5.1 (COM), U11.55 (GPIO44/ADC4)
ADC4: U8.1 (COM), U11.54 (GPIO43/ADC3)
ADC5: U3.1 (COM), U11.53 (GPIO42/ADC2)
ADC6: U6.1 (COM), U11.52 (GPIO41/ADC1)
ADC7: TP6.1 (1_1), U9.1 (COM), U11.49 (GPIO40/ADC0)
D+: J1.B6 (D+), R14.1, U1.6 (IO4)
D-: J1.B7 (D-), R13.2, U1.4 (IO3)
GND: C1.2, C2.2, C3.2, C4.2, C5.2, C6.2, C7.2, C8.2, C9.2, C10.2, C11.2, C12.2, C13.2, C14.2, C15.2, C16.2, C17.2, C18.2, C19.2, C20.2, C21.2, C22.2, C23.2, C24.1, C25.2, C26.2, C27.2, C28.2, C29.2, C30.2, C31.2, C32.2, C33.2, C34.2, C35.2, C36.2, C37.2, C38.2, J1.A1 (GND), J1.A12 (GND), J1.B1 (GND), J1.B12 (GND), J1.SH (SHIELD), J2.1, R1.1, R2.1, R3.1, R4.1, R5.1, R6.1, R7.1, R8.1, R9.1, R10.1, R11.2, R12.2, TP1.1 (1_1), U1.2 (VN), U2.12 (GND), U2.16 (I15), U3.12 (GND), U3.16 (I15), U4.12 (GND), U4.16 (I15), U5.12 (GND), U5.16 (I15), U6.12 (GND), U6.16 (I15), U7.12 (GND), U7.16 (I15), U8.12 (GND), U8.16 (I15), U9.12 (GND), U9.16 (I15), U10.1 (GND), U11.62 (VREG_PGND), U11.65 (VREG_FB), U11.81 (GND), U12.2 (GND), Y1.2 (G), Y1.4 (G); also elsewhere on the board
I0A: U4.9 (I0); also elsewhere on the board
I0B: U7.9 (I0); also elsewhere on the board
I0C: U2.9 (I0); also elsewhere on the board
I0D: U5.9 (I0); also elsewhere on the board
I0E: U8.9 (I0); also elsewhere on the board
I0F: U3.9 (I0); also elsewhere on the board
I0G: U6.9 (I0); also elsewhere on the board
I0H: U9.9 (I0); also elsewhere on the board
I1A: U4.8 (I1); also elsewhere on the board
I1B: U7.8 (I1); also elsewhere on the board
I1C: U2.8 (I1); also elsewhere on the board
I1D: U5.8 (I1); also elsewhere on the board
I1E: U8.8 (I1); also elsewhere on the board
I1F: U3.8 (I1); also elsewhere on the board
I1G: U6.8 (I1); also elsewhere on the board
I1H: U9.8 (I1); also elsewhere on the board
I2A: U4.7 (I2); also elsewhere on the board
I2B: U7.7 (I2); also elsewhere on the board
I2C: U2.7 (I2); also elsewhere on the board
I2D: U5.7 (I2); also elsewhere on the board
I2E: U8.7 (I2); also elsewhere on the board
I2F: U3.7 (I2); also elsewhere on the board
I2G: U6.7 (I2); also elsewhere on the board
I2H: U9.7 (I2); also elsewhere on the board
I3A: U4.6 (I3); also elsewhere on the board
I3B: U7.6 (I3); also elsewhere on the board
I3C: U2.6 (I3); also elsewhere on the board
I3D: U5.6 (I3); also elsewhere on the board
I3E: U8.6 (I3); also elsewhere on the board
I3F: U3.6 (I3); also elsewhere on the board
I3G: U6.6 (I3); also elsewhere on the board
I3H: U9.6 (I3); also elsewhere on the board
I4A: U4.5 (I4); also elsewhere on the board
I4B: U7.5 (I4); also elsewhere on the board
I4C: U2.5 (I4); also elsewhere on the board
I4D: U5.5 (I4); also elsewhere on the board
I4E: U8.5 (I4); also elsewhere on the board
I4F: U3.5 (I4); also elsewhere on the board
I4G: U6.5 (I4); also elsewhere on the board
I4H: U9.5 (I4); also elsewhere on the board
I5A: U4.4 (I5); also elsewhere on the board
I5B: TP3.1 (1_1), U7.17 (I14); also elsewhere on the board
I5C: U2.4 (I5); also elsewhere on the board
I5D: U5.17 (I14); also elsewhere on the board
I5E: U8.4 (I5); also elsewhere on the board
I5F: U3.17 (I14); also elsewhere on the board
I5G: U6.4 (I5); also elsewhere on the board
I5H: U9.17 (I14); also elsewhere on the board
I6A: U4.3 (I6); also elsewhere on the board
I6B: U7.18 (I13); also elsewhere on the board
I6C: U2.3 (I6); also elsewhere on the board
I6D: U5.18 (I13); also elsewhere on the board
I6E: U8.3 (I6); also elsewhere on the board
I6F: U3.18 (I13); also elsewhere on the board
I6G: U6.3 (I6); also elsewhere on the board
I6H: U9.18 (I13); also elsewhere on the board
I7A: U4.2 (I7); also elsewhere on the board
I7B: U7.19 (I12); also elsewhere on the board
I7C: U2.2 (I7); also elsewhere on the board
I7D: U5.19 (I12); also elsewhere on the board
I7E: U8.2 (I7); also elsewhere on the board
I7F: U3.19 (I12); also elsewhere on the board
I7G: U6.2 (I7); also elsewhere on the board
I7H: U9.19 (I12); also elsewhere on the board
I8A: U4.23 (I8); also elsewhere on the board
I8B: U7.20 (I11); also elsewhere on the board
I8C: U2.23 (I8); also elsewhere on the board
I8D: U5.20 (I11); also elsewhere on the board
I8E: U8.23 (I8); also elsewhere on the board
I8F: U3.20 (I11); also elsewhere on the board
I8G: U6.23 (I8); also elsewhere on the board
I8H: U9.20 (I11); also elsewhere on the board
I9A: U4.22 (I9); also elsewhere on the board
I9B: U7.21 (I10); also elsewhere on the board
I9C: U2.22 (I9); also elsewhere on the board
I9D: U5.21 (I10); also elsewhere on the board
I9E: U8.22 (I9); also elsewhere on the board
I9F: U3.21 (I10); also elsewhere on the board
I9G: U6.22 (I9); also elsewhere on the board
I9H: U9.21 (I10); also elsewhere on the board
I10A: U4.17 (I14); also elsewhere on the board
I10B: U7.22 (I9); also elsewhere on the board
I10C: U2.17 (I14); also elsewhere on the board
I10D: U5.22 (I9); also elsewhere on the board
I10E: U8.17 (I14); also elsewhere on the board
I10F: U3.22 (I9); also elsewhere on the board
I10G: U6.17 (I14); also elsewhere on the board
I10H: U9.22 (I9); also elsewhere on the board
I11A: U4.18 (I13); also elsewhere on the board
I11B: U7.23 (I8); also elsewhere on the board
I11C: U2.18 (I13); also elsewhere on the board
I11D: U5.23 (I8); also elsewhere on the board
I11E: U8.18 (I13); also elsewhere on the board
I11F: U3.23 (I8); also elsewhere on the board
I11G: U6.18 (I13); also elsewhere on the board
I11H: U9.23 (I8); also elsewhere on the board
I12A: U4.19 (I12); also elsewhere on the board
I12B: U7.2 (I7); also elsewhere on the board
I12C: U2.19 (I12); also elsewhere on the board
I12D: U5.2 (I7); also elsewhere on the board
I12E: U8.19 (I12); also elsewhere on the board
I12F: U3.2 (I7); also elsewhere on the board
I12G: U6.19 (I12); also elsewhere on the board
I12H: U9.2 (I7); also elsewhere on the board
I13A: U4.20 (I11); also elsewhere on the board
I13B: U7.3 (I6); also elsewhere on the board
I13C: U2.20 (I11); also elsewhere on the board
I13D: U5.3 (I6); also elsewhere on the board
I13E: U8.20 (I11); also elsewhere on the board
I13F: U3.3 (I6); also elsewhere on the board
I13G: U6.20 (I11); also elsewhere on the board
I13H: U9.3 (I6); also elsewhere on the board
I14A: U4.21 (I10); also elsewhere on the board
I14B: U7.4 (I5); also elsewhere on the board
I14C: U2.21 (I10); also elsewhere on the board
I14D: U5.4 (I5); also elsewhere on the board
I14E: U8.21 (I10); also elsewhere on the board
I14F: U3.4 (I5); also elsewhere on the board
I14G: U6.21 (I10); also elsewhere on the board
I14H: U9.4 (I5); also elsewhere on the board
unnamed: C25.1, R15.1, Y1.3
unnamed: J2.2, U11.34 (SWDIO)
unnamed: J2.4, U11.33 (SWCLK)
unnamed: R11.1, SW2.1
unnamed: R12.1, SW1.1
unnamed: C17.1, C19.1, F1.2, TP4.1 (1_1), U10.3 (VI)
unnamed: C29.1, C32.1, FB1.2, U11.59 (ADC_AVDD)
unnamed: SW2.2, U11.35 (RUN)
unnamed: R13.1, U11.66 (USB_DM)
unnamed: R14.2, U11.67 (USB_DP)
unnamed: C24.2, U11.30 (XIN), Y1.1
unnamed: R15.2, U11.31 (XOUT)
unnamed: SW1.2, U11.75 (~QSPI_SS)
VBUS: F1.1, J1.A4 (VBUS), J1.A9 (VBUS), J1.B4 (VBUS), J1.B9 (VBUS), U1.5 (VP)
~EN0: R5.2, TP2.1 (1_1), U4.15 (~E)
~EN1: R8.2, U7.15 (~E)
~EN2: R1.2, U2.15 (~E)
~EN3: R6.2, U5.15 (~E)
~EN4: R9.2, U8.15 (~E)
~EN5: R2.2, U3.15 (~E)
~EN6: R7.2, U6.15 (~E)
~EN7: R10.2, U9.15 (~E)

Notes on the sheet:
HALL SENSOR MULTIPLEXER F
HALL SENSOR MULTIPLEXER B
HALL SENSOR MULTIPLEXER A
Drop-in replacement with BL9110-330BPFB for lower Vdrop.
HALL SENSOR MULTIPLEXER C
RP2354B
C(crystal) = 10pF C(stray) = ~3pF C(load) = 2 * (10 - 3) = 2 * 7 = 14pF (~15pF E12) NOTE: Keep traces short
600R 100MHz
5V -> 3.3V LDO
Right angle
3.3V -> 1.1V LDO
HALL SENSOR MULTIPLEXER H
MICROCONTROLLER
USB CONNECTOR
HALL SENSOR MULTIPLEXER D
HALL SENSOR MULTIPLEXER E
HALL SENSOR MULTIPLEXER G

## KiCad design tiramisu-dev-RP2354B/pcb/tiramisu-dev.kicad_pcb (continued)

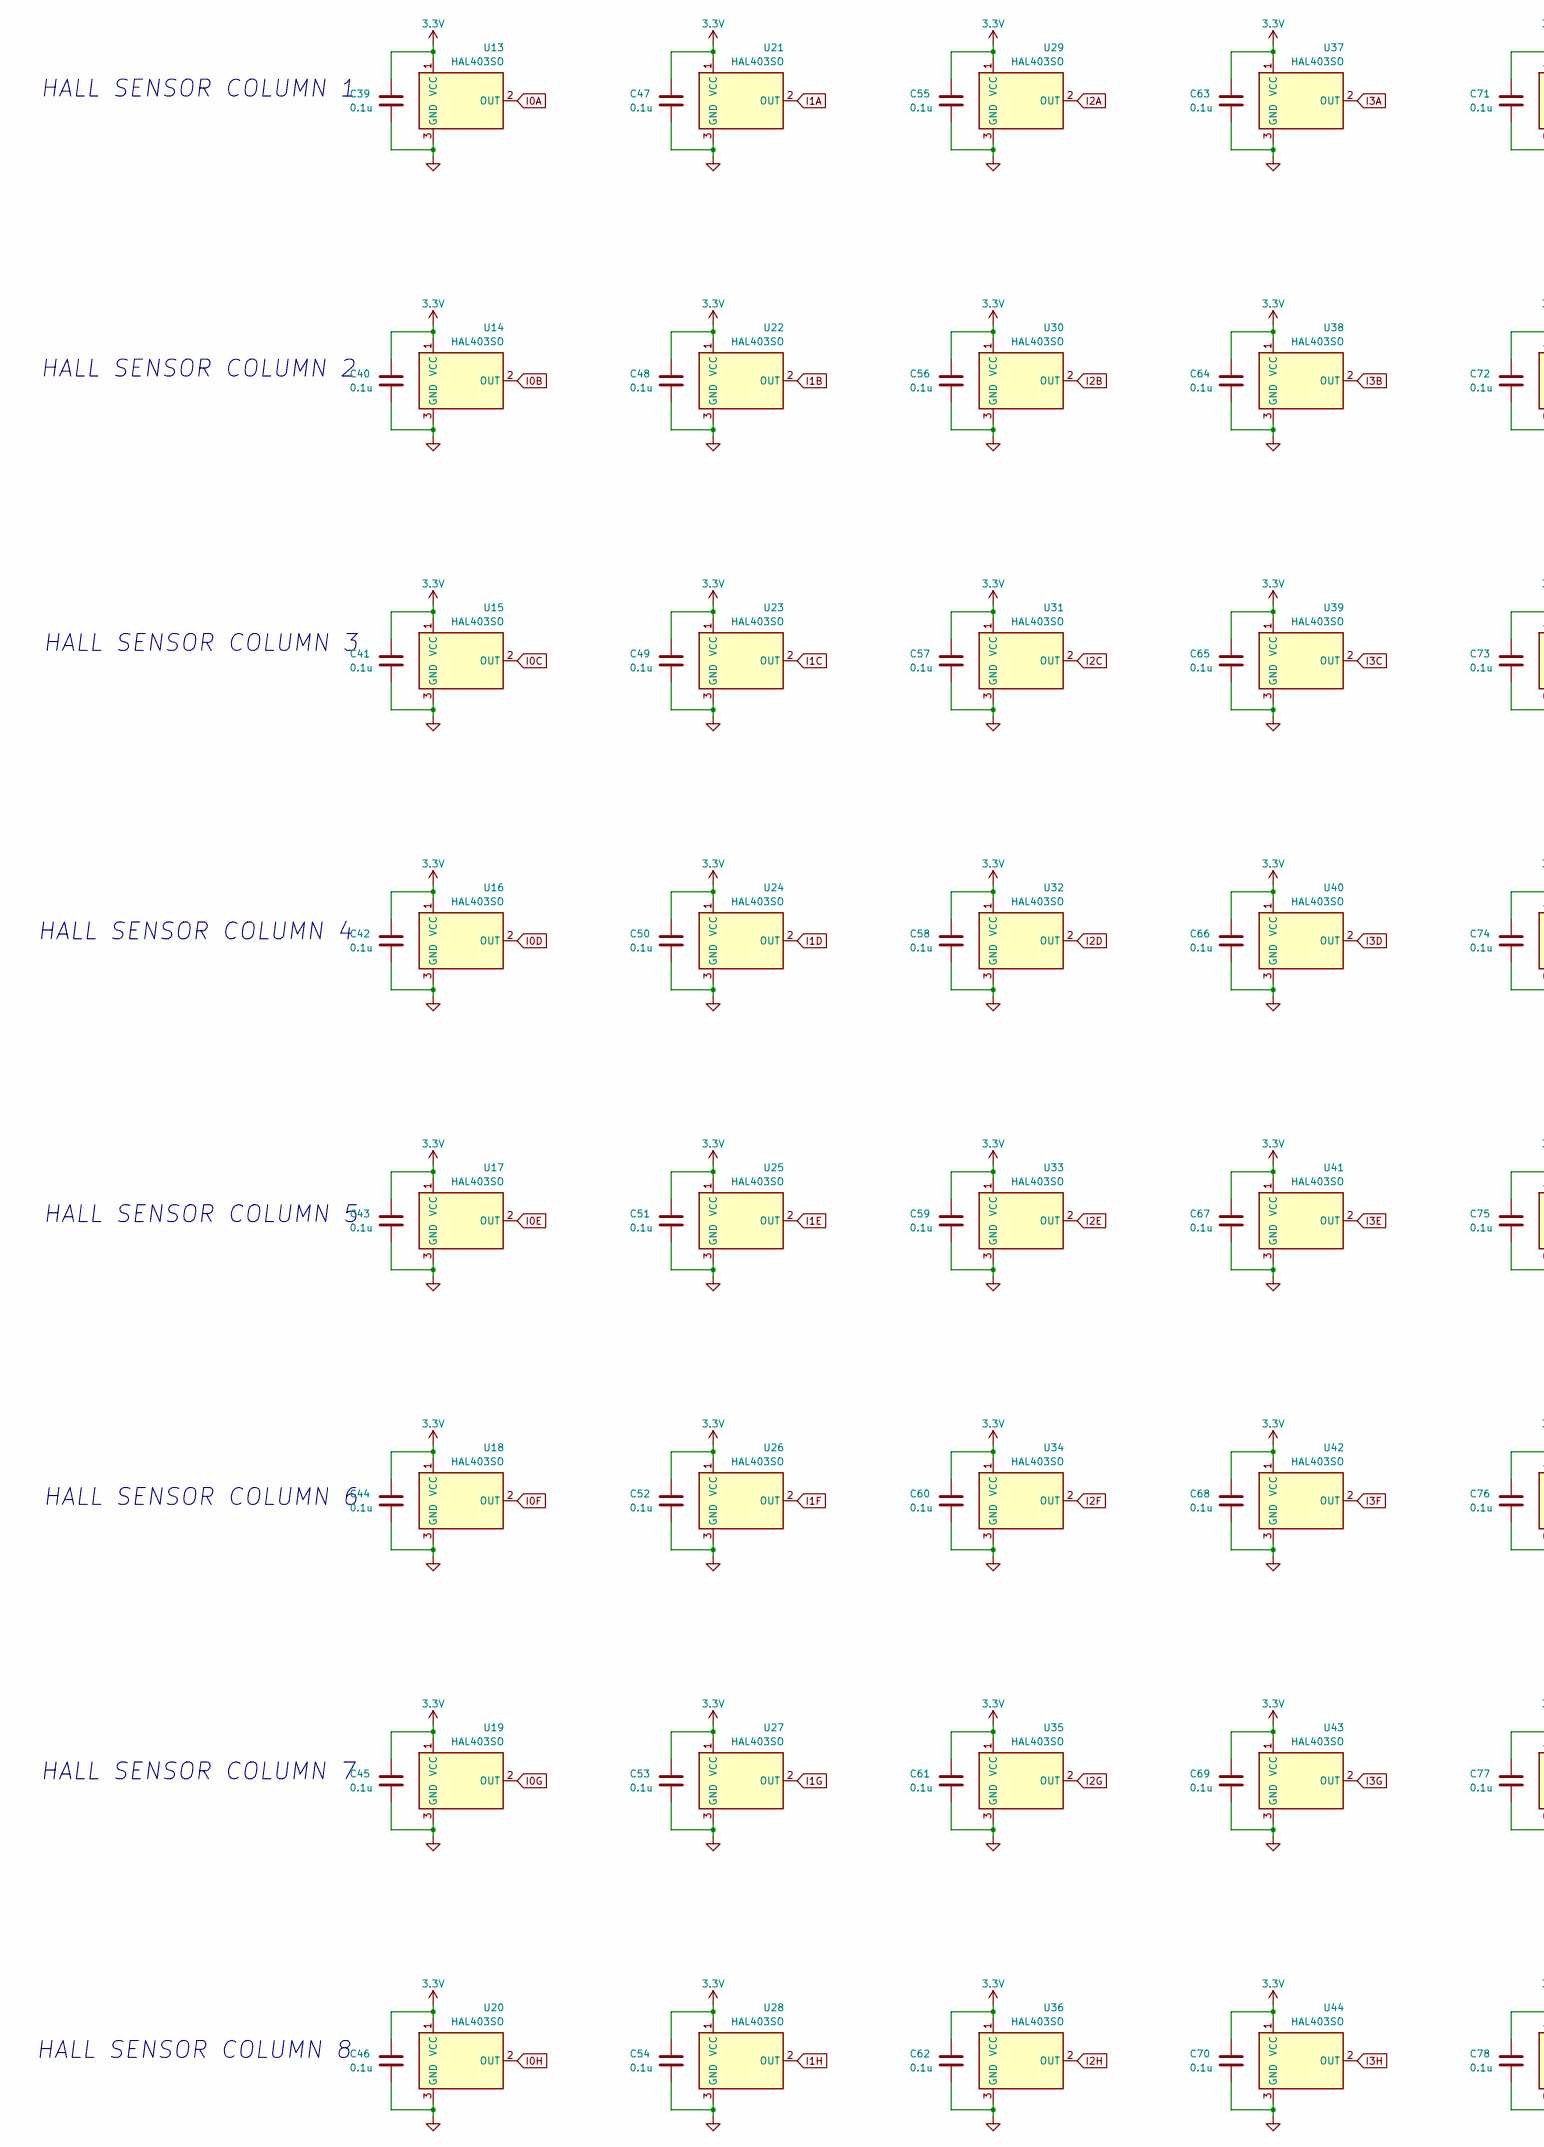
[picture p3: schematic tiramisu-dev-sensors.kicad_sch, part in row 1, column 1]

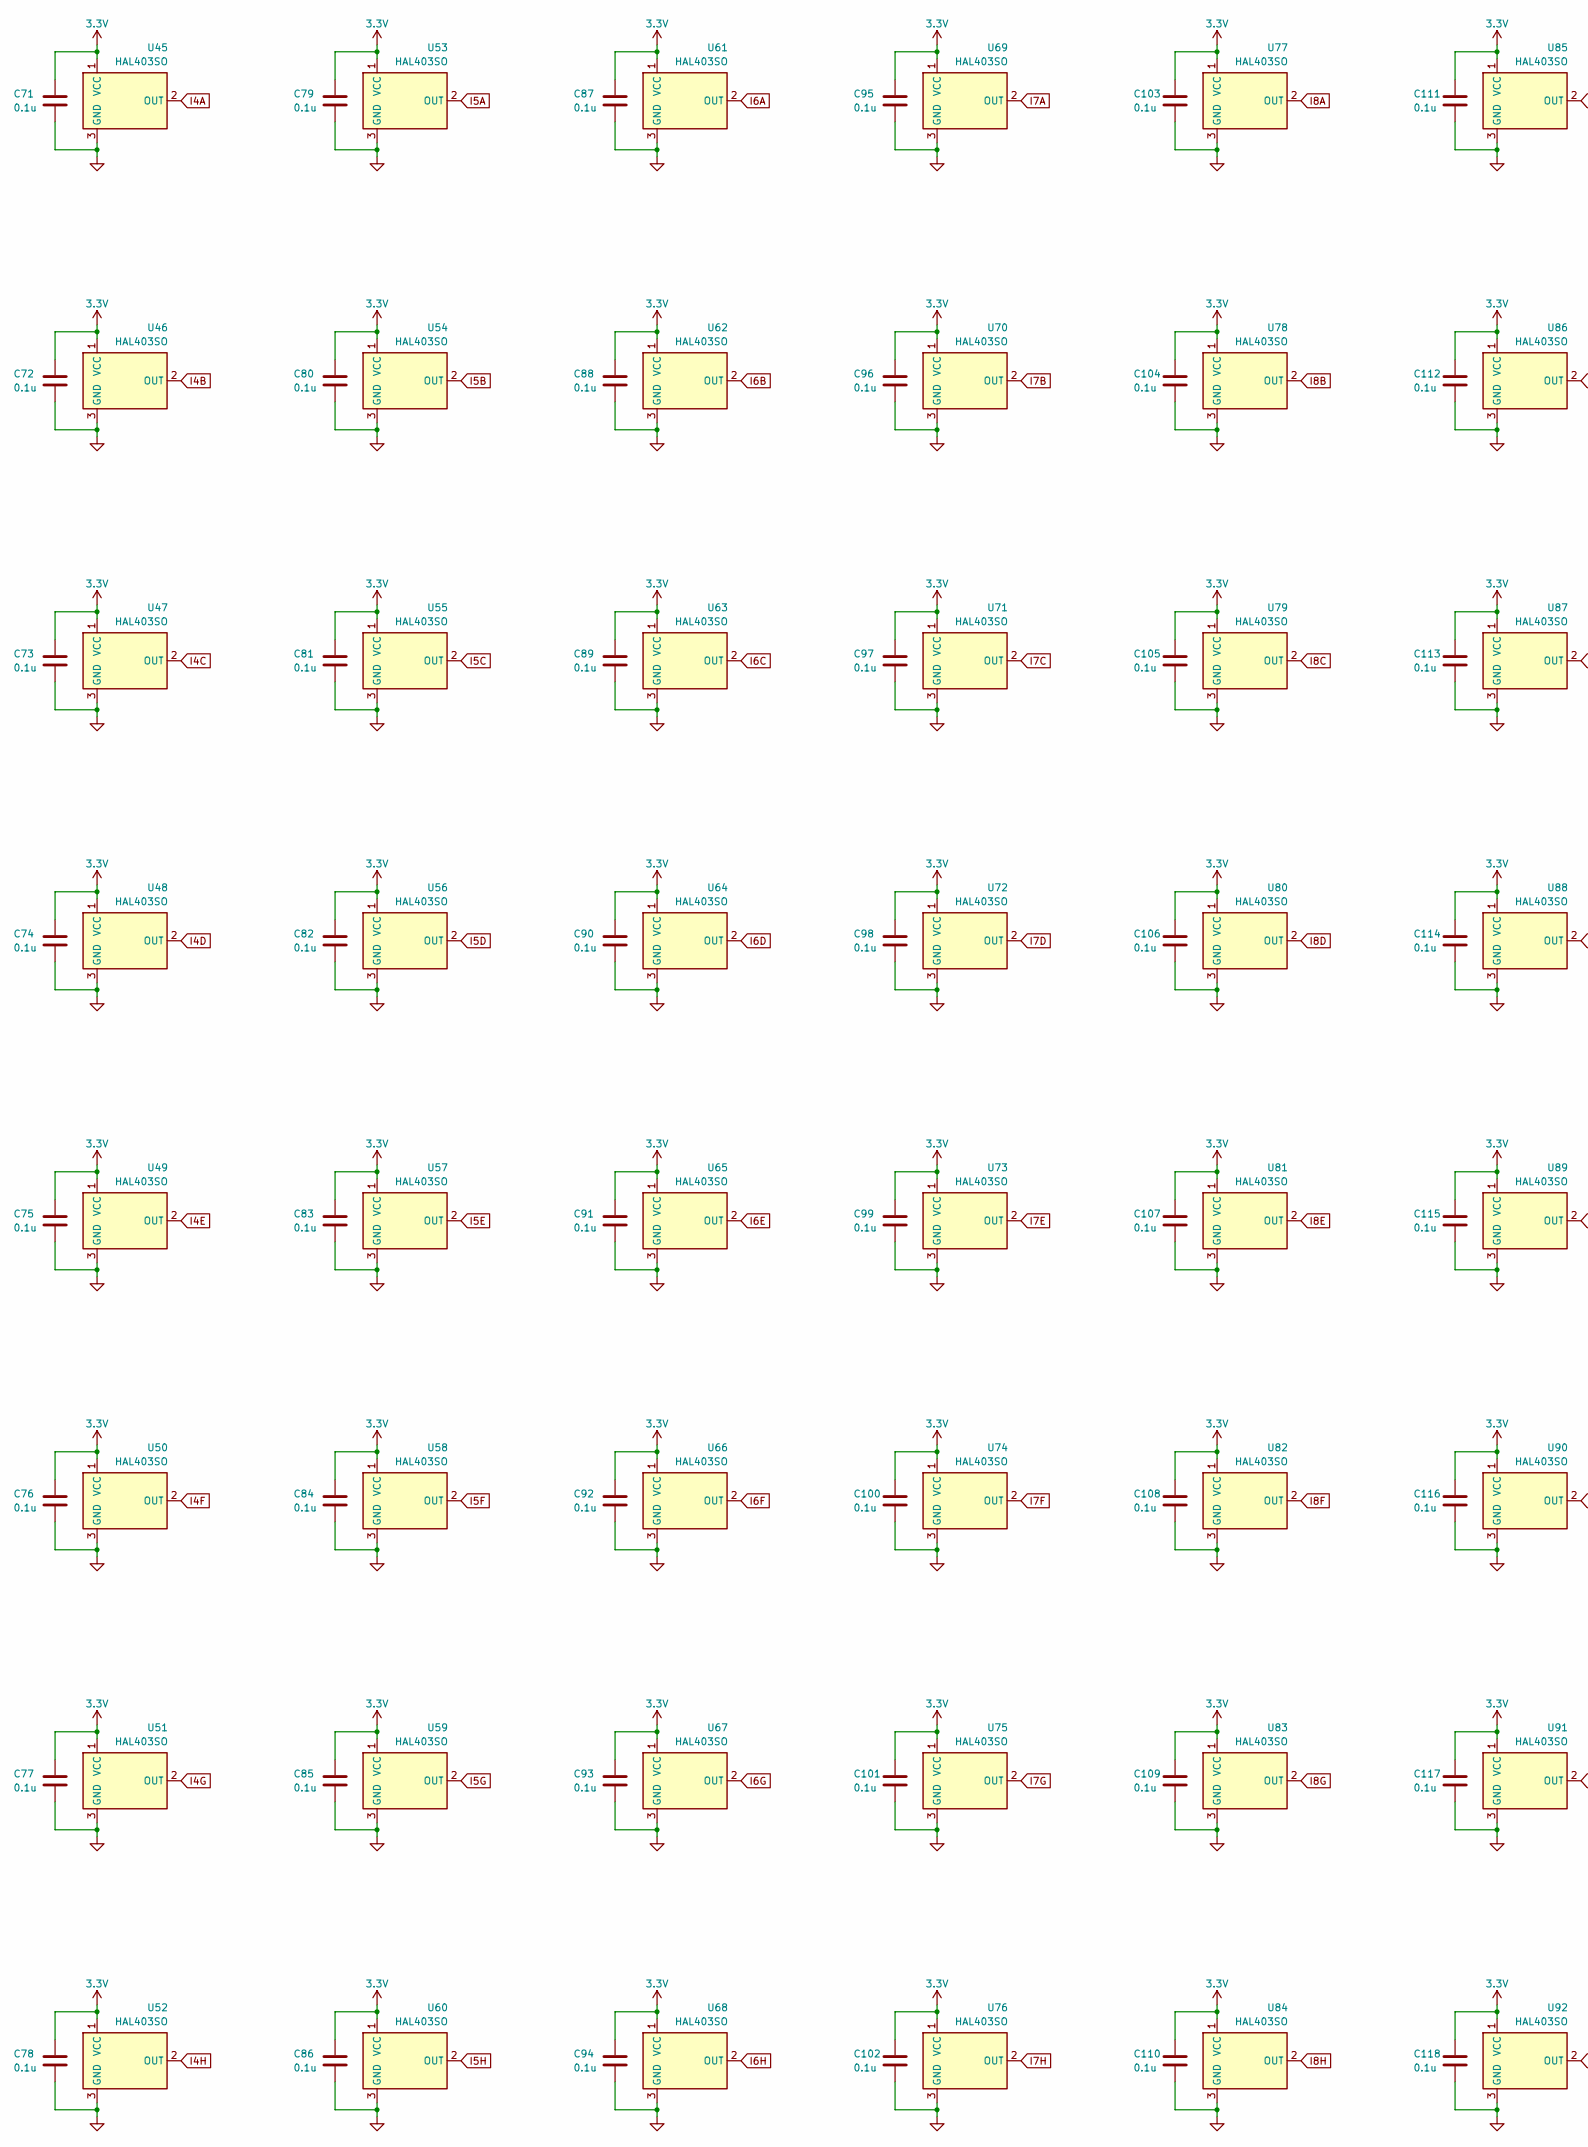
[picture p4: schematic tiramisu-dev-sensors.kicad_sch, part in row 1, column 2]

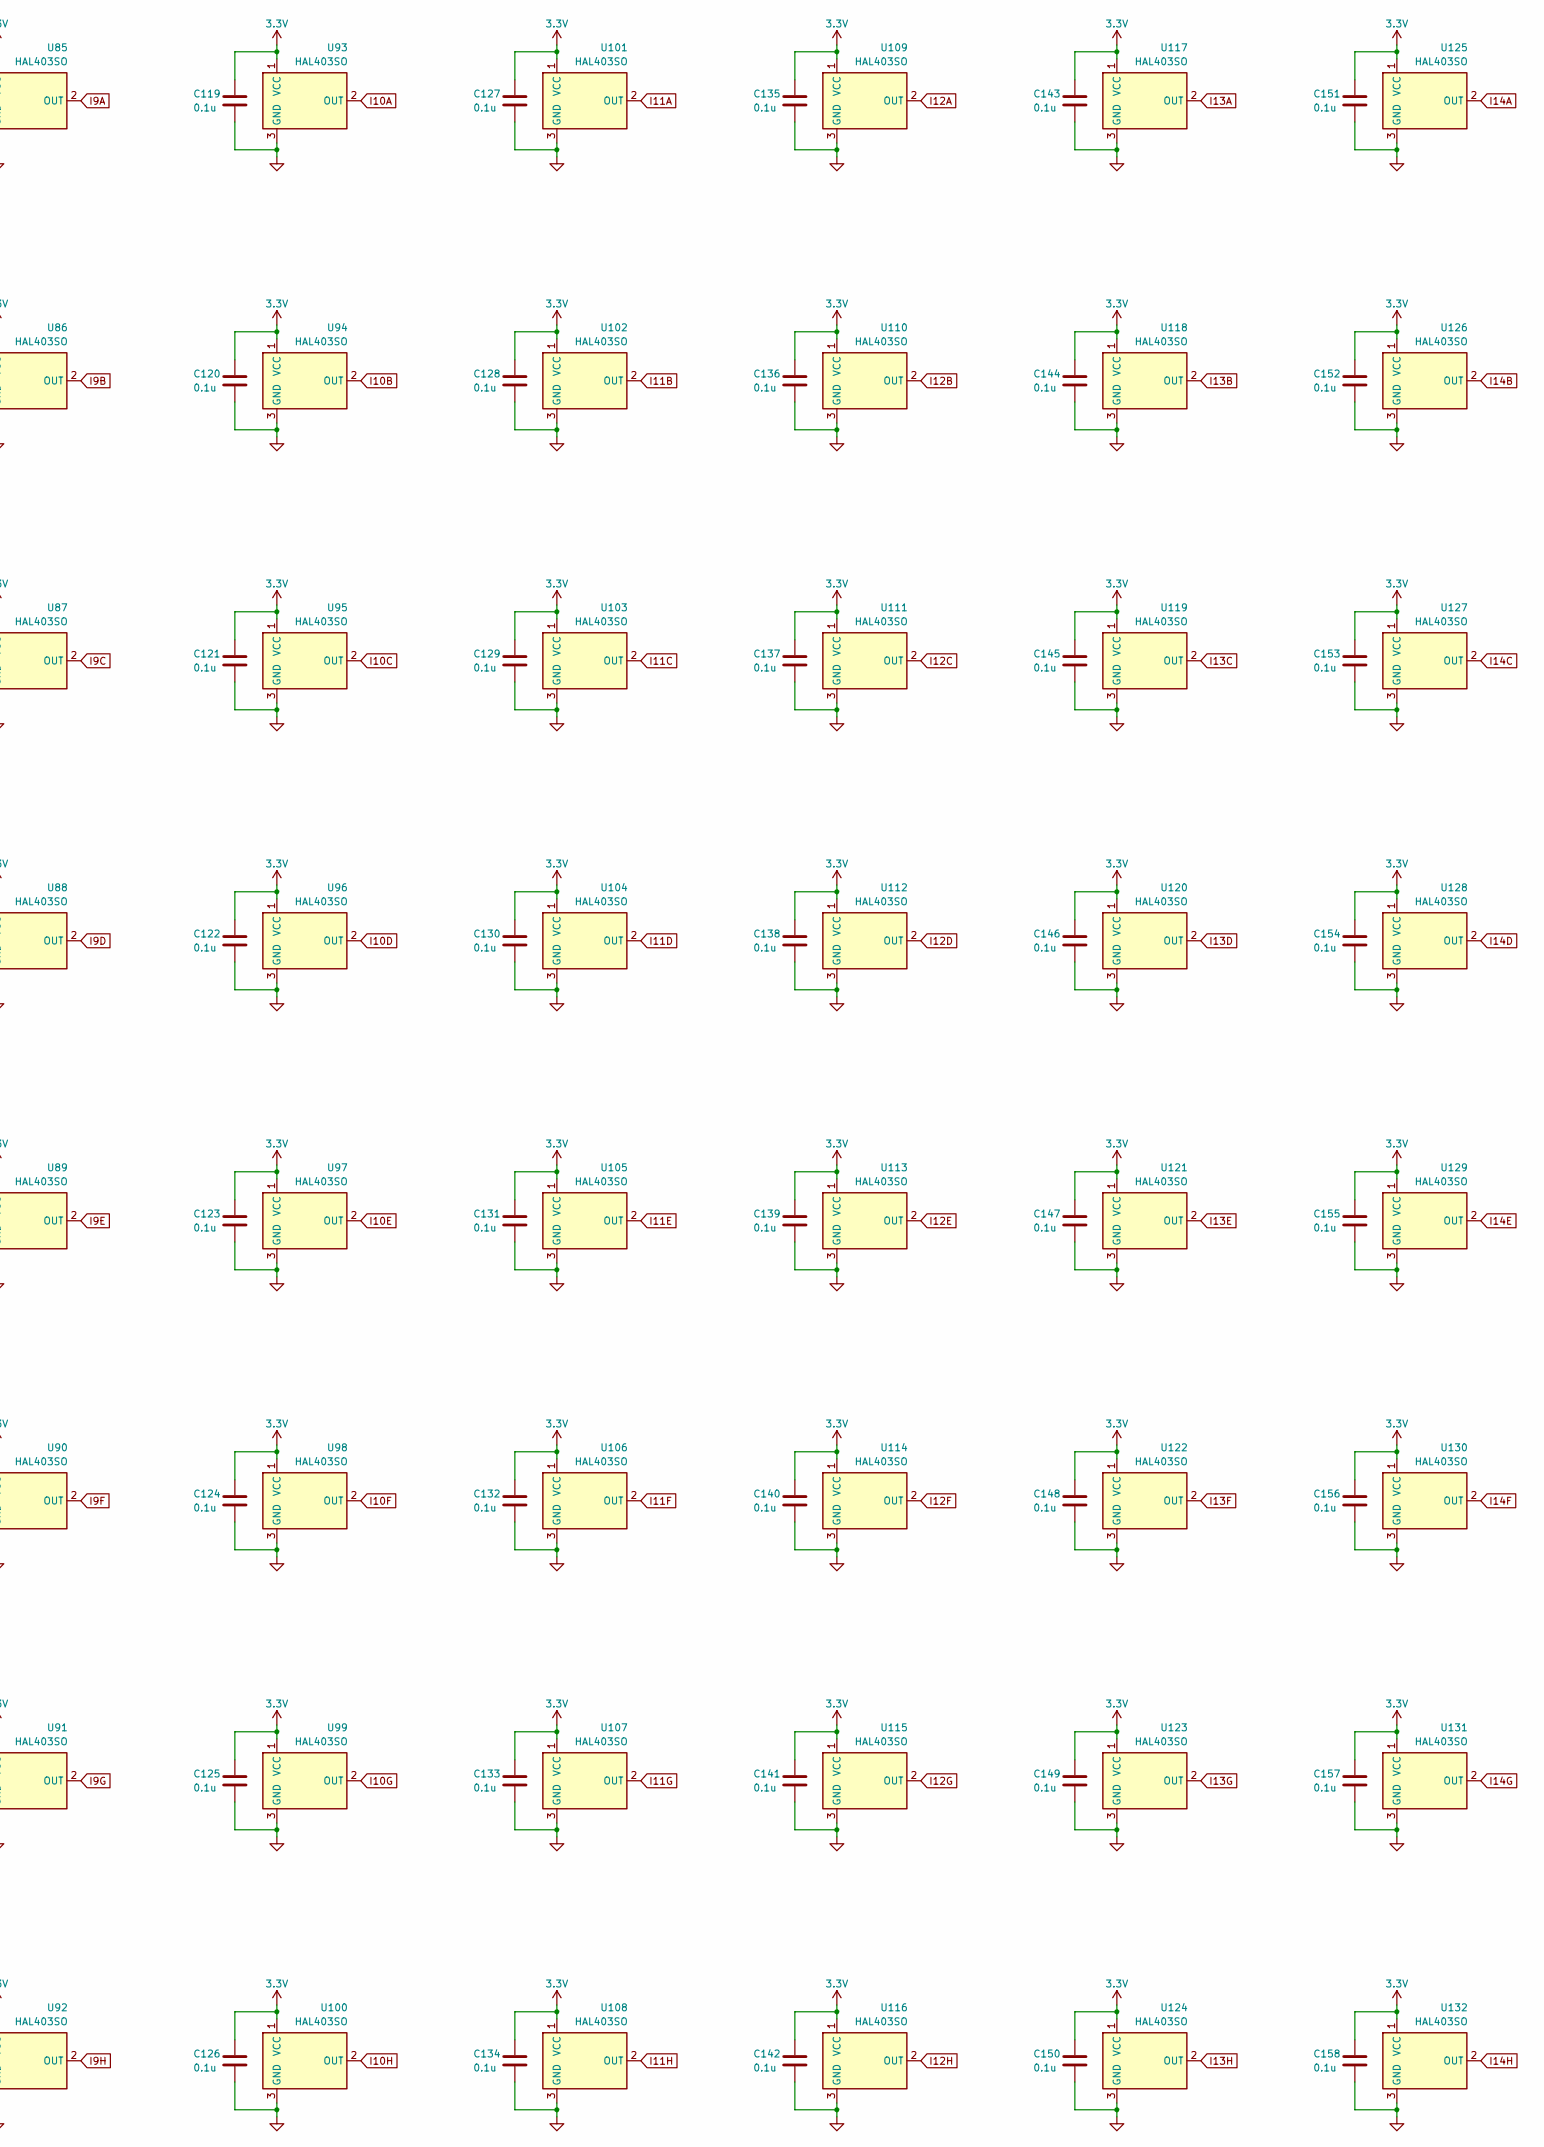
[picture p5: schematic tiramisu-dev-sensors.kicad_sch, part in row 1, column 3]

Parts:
C39, C40, C41, C42, C43, C44, C45, C46, C47, C48, C49, C50, C51, C52, C53, C54, C55, C56, C57, C58, C59, C60, C61, C62, C63, C64, C65, C66, C67, C68, C69, C70, C71, C72, C73, C74, C75, C76, C77, C78, C79, C80, C81, C82, C83, C84, C85, C86, C87, C88, C89, C90, C91, C92, C93, C94, C95, C96, C97, C98, C99, C100, C101, C102, C103, C104, C105, C106, C107, C108, C109, C110, C111, C112, C113, C114, C115, C116, C117, C118, C119, C120, C121, C122, C123, C124, C125, C126, C127, C128, C129, C130, C131, C132, C133, C134, C135, C136, C137, C138, C139, C140, C141, C142, C143, C144, C145, C146, C147, C148, C149, C150, C151, C152, C153, C154, C155, C156, C157, C158: 0.1u; C_0603_1608Metric
U13, U14, U15, U16, U17, U18, U19, U20, U21, U22, U23, U24, U25, U26, U27, U28, U29, U30, U31, U32, U33, U34, U35, U36, U37, U38, U39, U40, U41, U42, U43, U44, U45, U46, U47, U48, U49, U50, U51, U52, U53, U54, U55, U56, U57, U58, U59, U60, U61, U62, U63, U64, U65, U66, U67, U68, U69, U70, U71, U72, U73, U74, U75, U76, U77, U78, U79, U80, U81, U82, U83, U84, U85, U86, U87, U88, U89, U90, U91, U92, U93, U94, U95, U96, U97, U98, U99, U100, U101, U102, U103, U104, U105, U106, U107, U108, U109, U110, U111, U112, U113, U114, U115, U116, U117, U118, U119, U120, U121, U122, U123, U124, U125, U126, U127, U128, U129, U130, U131, U132: HAL403SO; SOT-23

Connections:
3.3V: C39.1, C40.1, C41.1, C42.1, C43.1, C44.1, C45.1, C46.1, C47.1, C48.1, C49.1, C50.1, C51.1, C52.1, C53.1, C54.1, C55.1, C56.1, C57.1, C58.1, C59.1, C60.1, C61.1, C62.1, C63.1, C64.1, C65.1, C66.1, C67.1, C68.1, C69.1, C70.1, C71.1, C72.1, C73.1, C74.1, C75.1, C76.1, C77.1, C78.1, C79.1, C80.1, C81.1, C82.1, C83.1, C84.1, C85.1, C86.1, C87.1, C88.1, C89.1, C90.1, C91.1, C92.1, C93.1, C94.1, C95.1, C96.1, C97.1, C98.1, C99.1, C100.1, C101.1, C102.1, C103.1, C104.1, C105.1, C106.1, C107.1, C108.1, C109.1, C110.1, C111.1, C112.1, C113.1, C114.1, C115.1, C116.1, C117.1, C118.1, C119.1, C120.1, C121.1, C122.1, C123.1, C124.1, C125.1, C126.1, C127.1, C128.1, C129.1, C130.1, C131.1, C132.1, C133.1, C134.1, C135.1, C136.1, C137.1, C138.1, C139.1, C140.1, C141.1, C142.1, C143.1, C144.1, C145.1, C146.1, C147.1, C148.1, C149.1, C150.1, C151.1, C152.1, C153.1, C154.1, C155.1, C156.1, C157.1, C158.1, U13.1 (VCC), U14.1 (VCC), U15.1 (VCC), U16.1 (VCC), U17.1 (VCC), U18.1 (VCC), U19.1 (VCC), U20.1 (VCC), U21.1 (VCC), U22.1 (VCC), U23.1 (VCC), U24.1 (VCC), U25.1 (VCC), U26.1 (VCC), U27.1 (VCC), U28.1 (VCC), U29.1 (VCC), U30.1 (VCC), U31.1 (VCC), U32.1 (VCC), U33.1 (VCC), U34.1 (VCC), U35.1 (VCC), U36.1 (VCC), U37.1 (VCC), U38.1 (VCC), U39.1 (VCC), U40.1 (VCC), U41.1 (VCC), U42.1 (VCC), U43.1 (VCC), U44.1 (VCC), U45.1 (VCC), U46.1 (VCC), U47.1 (VCC), U48.1 (VCC), U49.1 (VCC), U50.1 (VCC), U51.1 (VCC), U52.1 (VCC), U53.1 (VCC), U54.1 (VCC), U55.1 (VCC), U56.1 (VCC), U57.1 (VCC), U58.1 (VCC), U59.1 (VCC), U60.1 (VCC), U61.1 (VCC), U62.1 (VCC), U63.1 (VCC), U64.1 (VCC), U65.1 (VCC), U66.1 (VCC), U67.1 (VCC), U68.1 (VCC), U69.1 (VCC), U70.1 (VCC), U71.1 (VCC), U72.1 (VCC), U73.1 (VCC), U74.1 (VCC), U75.1 (VCC), U76.1 (VCC), U77.1 (VCC), U78.1 (VCC), U79.1 (VCC), U80.1 (VCC), U81.1 (VCC), U82.1 (VCC), U83.1 (VCC), U84.1 (VCC), U85.1 (VCC), U86.1 (VCC), U87.1 (VCC), U88.1 (VCC), U89.1 (VCC), U90.1 (VCC), U91.1 (VCC), U92.1 (VCC), U93.1 (VCC), U94.1 (VCC), U95.1 (VCC), U96.1 (VCC), U97.1 (VCC), U98.1 (VCC), U99.1 (VCC), U100.1 (VCC), U101.1 (VCC), U102.1 (VCC), U103.1 (VCC), U104.1 (VCC), U105.1 (VCC), U106.1 (VCC), U107.1 (VCC), U108.1 (VCC), U109.1 (VCC), U110.1 (VCC), U111.1 (VCC), U112.1 (VCC), U113.1 (VCC), U114.1 (VCC), U115.1 (VCC), U116.1 (VCC), U117.1 (VCC), U118.1 (VCC), U119.1 (VCC), U120.1 (VCC), U121.1 (VCC), U122.1 (VCC), U123.1 (VCC), U124.1 (VCC), U125.1 (VCC), U126.1 (VCC), U127.1 (VCC), U128.1 (VCC), U129.1 (VCC), U130.1 (VCC), U131.1 (VCC), U132.1 (VCC); also elsewhere on the board
GND: C39.2, C40.2, C41.2, C42.2, C43.2, C44.2, C45.2, C46.2, C47.2, C48.2, C49.2, C50.2, C51.2, C52.2, C53.2, C54.2, C55.2, C56.2, C57.2, C58.2, C59.2, C60.2, C61.2, C62.2, C63.2, C64.2, C65.2, C66.2, C67.2, C68.2, C69.2, C70.2, C71.2, C72.2, C73.2, C74.2, C75.2, C76.2, C77.2, C78.2, C79.2, C80.2, C81.2, C82.2, C83.2, C84.2, C85.2, C86.2, C87.2, C88.2, C89.2, C90.2, C91.2, C92.2, C93.2, C94.2, C95.2, C96.2, C97.2, C98.2, C99.2, C100.2, C101.2, C102.2, C103.2, C104.2, C105.2, C106.2, C107.2, C108.2, C109.2, C110.2, C111.2, C112.2, C113.2, C114.2, C115.2, C116.2, C117.2, C118.2, C119.2, C120.2, C121.2, C122.2, C123.2, C124.2, C125.2, C126.2, C127.2, C128.2, C129.2, C130.2, C131.2, C132.2, C133.2, C134.2, C135.2, C136.2, C137.2, C138.2, C139.2, C140.2, C141.2, C142.2, C143.2, C144.2, C145.2, C146.2, C147.2, C148.2, C149.2, C150.2, C151.2, C152.2, C153.2, C154.2, C155.2, C156.2, C157.2, C158.2, U13.3 (GND), U14.3 (GND), U15.3 (GND), U16.3 (GND), U17.3 (GND), U18.3 (GND), U19.3 (GND), U20.3 (GND), U21.3 (GND), U22.3 (GND), U23.3 (GND), U24.3 (GND), U25.3 (GND), U26.3 (GND), U27.3 (GND), U28.3 (GND), U29.3 (GND), U30.3 (GND), U31.3 (GND), U32.3 (GND), U33.3 (GND), U34.3 (GND), U35.3 (GND), U36.3 (GND), U37.3 (GND), U38.3 (GND), U39.3 (GND), U40.3 (GND), U41.3 (GND), U42.3 (GND), U43.3 (GND), U44.3 (GND), U45.3 (GND), U46.3 (GND), U47.3 (GND), U48.3 (GND), U49.3 (GND), U50.3 (GND), U51.3 (GND), U52.3 (GND), U53.3 (GND), U54.3 (GND), U55.3 (GND), U56.3 (GND), U57.3 (GND), U58.3 (GND), U59.3 (GND), U60.3 (GND), U61.3 (GND), U62.3 (GND), U63.3 (GND), U64.3 (GND), U65.3 (GND), U66.3 (GND), U67.3 (GND), U68.3 (GND), U69.3 (GND), U70.3 (GND), U71.3 (GND), U72.3 (GND), U73.3 (GND), U74.3 (GND), U75.3 (GND), U76.3 (GND), U77.3 (GND), U78.3 (GND), U79.3 (GND), U80.3 (GND), U81.3 (GND), U82.3 (GND), U83.3 (GND), U84.3 (GND), U85.3 (GND), U86.3 (GND), U87.3 (GND), U88.3 (GND), U89.3 (GND), U90.3 (GND), U91.3 (GND), U92.3 (GND), U93.3 (GND), U94.3 (GND), U95.3 (GND), U96.3 (GND), U97.3 (GND), U98.3 (GND), U99.3 (GND), U100.3 (GND), U101.3 (GND), U102.3 (GND), U103.3 (GND), U104.3 (GND), U105.3 (GND), U106.3 (GND), U107.3 (GND), U108.3 (GND), U109.3 (GND), U110.3 (GND), U111.3 (GND), U112.3 (GND), U113.3 (GND), U114.3 (GND), U115.3 (GND), U116.3 (GND), U117.3 (GND), U118.3 (GND), U119.3 (GND), U120.3 (GND), U121.3 (GND), U122.3 (GND), U123.3 (GND), U124.3 (GND), U125.3 (GND), U126.3 (GND), U127.3 (GND), U128.3 (GND), U129.3 (GND), U130.3 (GND), U131.3 (GND), U132.3 (GND); also elsewhere on the board
I0A: U13.2 (OUT); also elsewhere on the board
I0B: U14.2 (OUT); also elsewhere on the board
I0C: U15.2 (OUT); also elsewhere on the board
I0D: U16.2 (OUT); also elsewhere on the board
I0E: U17.2 (OUT); also elsewhere on the board
I0F: U18.2 (OUT); also elsewhere on the board
I0G: U19.2 (OUT); also elsewhere on the board
I0H: U20.2 (OUT); also elsewhere on the board
I1A: U21.2 (OUT); also elsewhere on the board
I1B: U22.2 (OUT); also elsewhere on the board
I1C: U23.2 (OUT); also elsewhere on the board
I1D: U24.2 (OUT); also elsewhere on the board
I1E: U25.2 (OUT); also elsewhere on the board
I1F: U26.2 (OUT); also elsewhere on the board
I1G: U27.2 (OUT); also elsewhere on the board
I1H: U28.2 (OUT); also elsewhere on the board
I2A: U29.2 (OUT); also elsewhere on the board
I2B: U30.2 (OUT); also elsewhere on the board
I2C: U31.2 (OUT); also elsewhere on the board
I2D: U32.2 (OUT); also elsewhere on the board
I2E: U33.2 (OUT); also elsewhere on the board
I2F: U34.2 (OUT); also elsewhere on the board
I2G: U35.2 (OUT); also elsewhere on the board
I2H: U36.2 (OUT); also elsewhere on the board
I3A: U37.2 (OUT); also elsewhere on the board
I3B: U38.2 (OUT); also elsewhere on the board
I3C: U39.2 (OUT); also elsewhere on the board
I3D: U40.2 (OUT); also elsewhere on the board
I3E: U41.2 (OUT); also elsewhere on the board
I3F: U42.2 (OUT); also elsewhere on the board
I3G: U43.2 (OUT); also elsewhere on the board
I3H: U44.2 (OUT); also elsewhere on the board
I4A: U45.2 (OUT); also elsewhere on the board
I4B: U46.2 (OUT); also elsewhere on the board
I4C: U47.2 (OUT); also elsewhere on the board
I4D: U48.2 (OUT); also elsewhere on the board
I4E: U49.2 (OUT); also elsewhere on the board
I4F: U50.2 (OUT); also elsewhere on the board
I4G: U51.2 (OUT); also elsewhere on the board
I4H: U52.2 (OUT); also elsewhere on the board
I5A: U53.2 (OUT); also elsewhere on the board
I5B: U54.2 (OUT); also elsewhere on the board
I5C: U55.2 (OUT); also elsewhere on the board
I5D: U56.2 (OUT); also elsewhere on the board
I5E: U57.2 (OUT); also elsewhere on the board
I5F: U58.2 (OUT); also elsewhere on the board
I5G: U59.2 (OUT); also elsewhere on the board
I5H: U60.2 (OUT); also elsewhere on the board
I6A: U61.2 (OUT); also elsewhere on the board
I6B: U62.2 (OUT); also elsewhere on the board
I6C: U63.2 (OUT); also elsewhere on the board
I6D: U64.2 (OUT); also elsewhere on the board
I6E: U65.2 (OUT); also elsewhere on the board
I6F: U66.2 (OUT); also elsewhere on the board
I6G: U67.2 (OUT); also elsewhere on the board
I6H: U68.2 (OUT); also elsewhere on the board
I7A: U69.2 (OUT); also elsewhere on the board
I7B: U70.2 (OUT); also elsewhere on the board
I7C: U71.2 (OUT); also elsewhere on the board
I7D: U72.2 (OUT); also elsewhere on the board
I7E: U73.2 (OUT); also elsewhere on the board
I7F: U74.2 (OUT); also elsewhere on the board
I7G: U75.2 (OUT); also elsewhere on the board
I7H: U76.2 (OUT); also elsewhere on the board
I8A: U77.2 (OUT); also elsewhere on the board
I8B: U78.2 (OUT); also elsewhere on the board
I8C: U79.2 (OUT); also elsewhere on the board
I8D: U80.2 (OUT); also elsewhere on the board
I8E: U81.2 (OUT); also elsewhere on the board
I8F: U82.2 (OUT); also elsewhere on the board
I8G: U83.2 (OUT); also elsewhere on the board
I8H: U84.2 (OUT); also elsewhere on the board
I9A: U85.2 (OUT); also elsewhere on the board
I9B: U86.2 (OUT); also elsewhere on the board
I9C: U87.2 (OUT); also elsewhere on the board
I9D: U88.2 (OUT); also elsewhere on the board
I9E: U89.2 (OUT); also elsewhere on the board
I9F: U90.2 (OUT); also elsewhere on the board
I9G: U91.2 (OUT); also elsewhere on the board
I9H: U92.2 (OUT); also elsewhere on the board
I10A: U93.2 (OUT); also elsewhere on the board
I10B: U94.2 (OUT); also elsewhere on the board
I10C: U95.2 (OUT); also elsewhere on the board
I10D: U96.2 (OUT); also elsewhere on the board
I10E: U97.2 (OUT); also elsewhere on the board
I10F: U98.2 (OUT); also elsewhere on the board
I10G: U99.2 (OUT); also elsewhere on the board
I10H: U100.2 (OUT); also elsewhere on the board
I11A: U101.2 (OUT); also elsewhere on the board
I11B: U102.2 (OUT); also elsewhere on the board
I11C: U103.2 (OUT); also elsewhere on the board
I11D: U104.2 (OUT); also elsewhere on the board
I11E: U105.2 (OUT); also elsewhere on the board
I11F: U106.2 (OUT); also elsewhere on the board
I11G: U107.2 (OUT); also elsewhere on the board
I11H: U108.2 (OUT); also elsewhere on the board
I12A: U109.2 (OUT); also elsewhere on the board
I12B: U110.2 (OUT); also elsewhere on the board
I12C: U111.2 (OUT); also elsewhere on the board
I12D: U112.2 (OUT); also elsewhere on the board
I12E: U113.2 (OUT); also elsewhere on the board
I12F: U114.2 (OUT); also elsewhere on the board
I12G: U115.2 (OUT); also elsewhere on the board
I12H: U116.2 (OUT); also elsewhere on the board
I13A: U117.2 (OUT); also elsewhere on the board
I13B: U118.2 (OUT); also elsewhere on the board
I13C: U119.2 (OUT); also elsewhere on the board
I13D: U120.2 (OUT); also elsewhere on the board
I13E: U121.2 (OUT); also elsewhere on the board
I13F: U122.2 (OUT); also elsewhere on the board
I13G: U123.2 (OUT); also elsewhere on the board
I13H: U124.2 (OUT); also elsewhere on the board
I14A: U125.2 (OUT); also elsewhere on the board
I14B: U126.2 (OUT); also elsewhere on the board
I14C: U127.2 (OUT); also elsewhere on the board
I14D: U128.2 (OUT); also elsewhere on the board
I14E: U129.2 (OUT); also elsewhere on the board
I14F: U130.2 (OUT); also elsewhere on the board
I14G: U131.2 (OUT); also elsewhere on the board
I14H: U132.2 (OUT); also elsewhere on the board

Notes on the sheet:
HALL SENSOR COLUMN 3
HALL SENSOR COLUMN 1
HALL SENSOR COLUMN 6
HALL SENSOR COLUMN 4
HALL SENSOR COLUMN 2
HALL SENSOR COLUMN 5
HALL SENSOR COLUMN 8
HALL SENSOR COLUMN 7

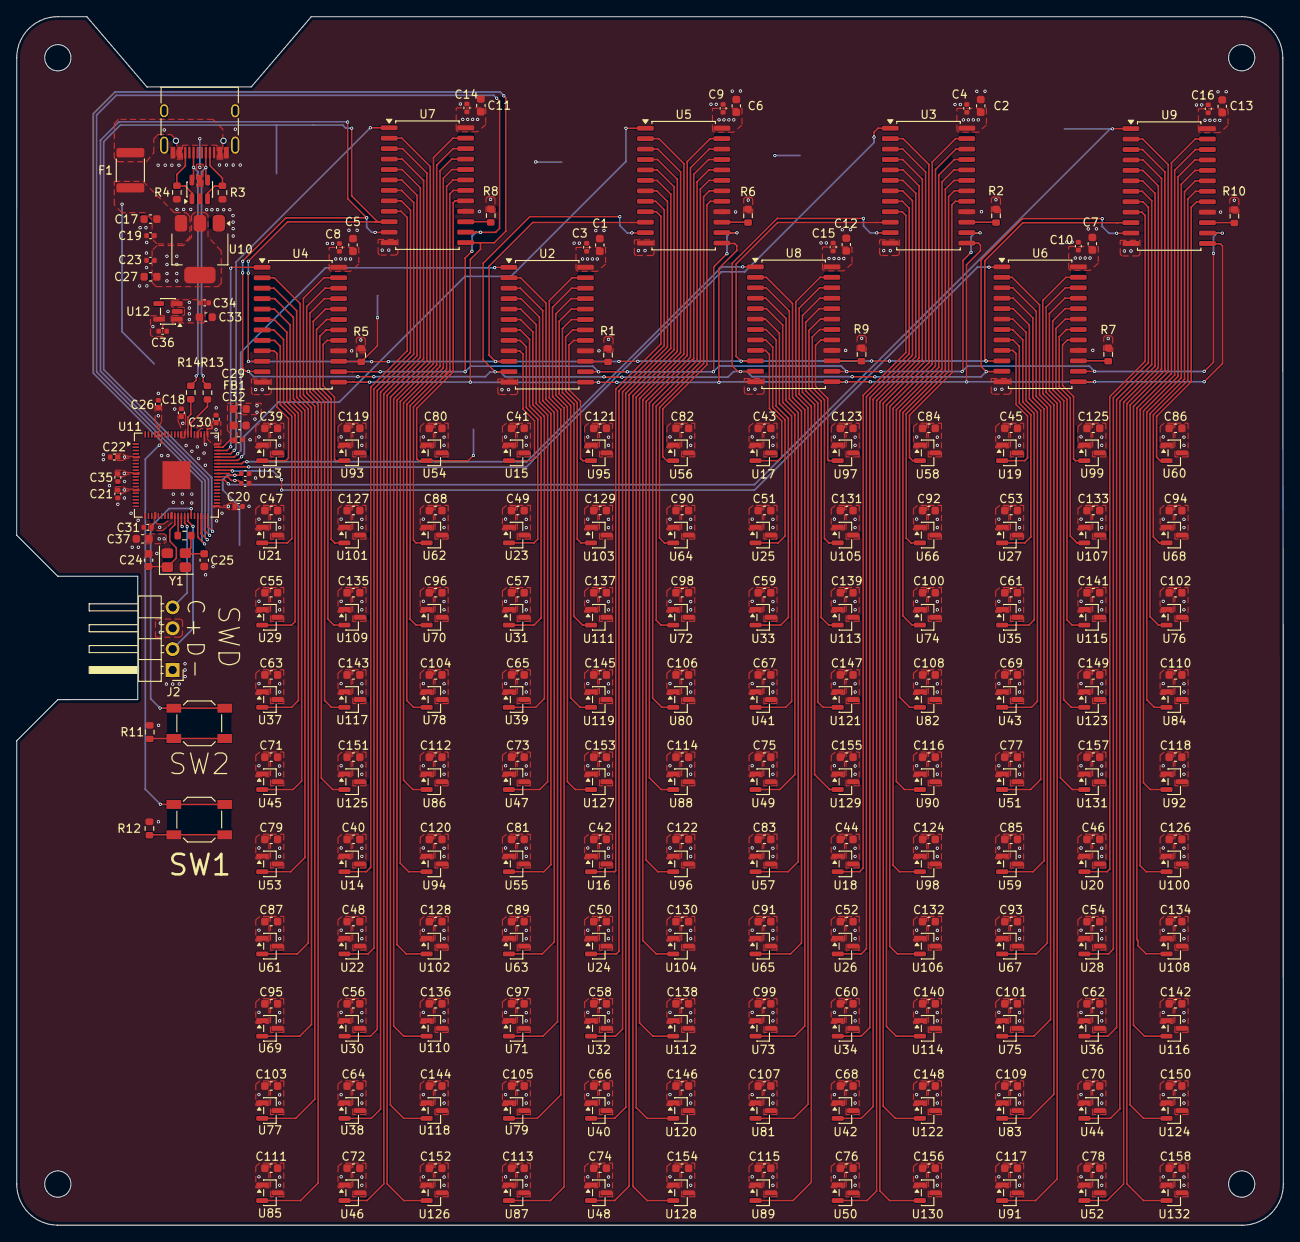
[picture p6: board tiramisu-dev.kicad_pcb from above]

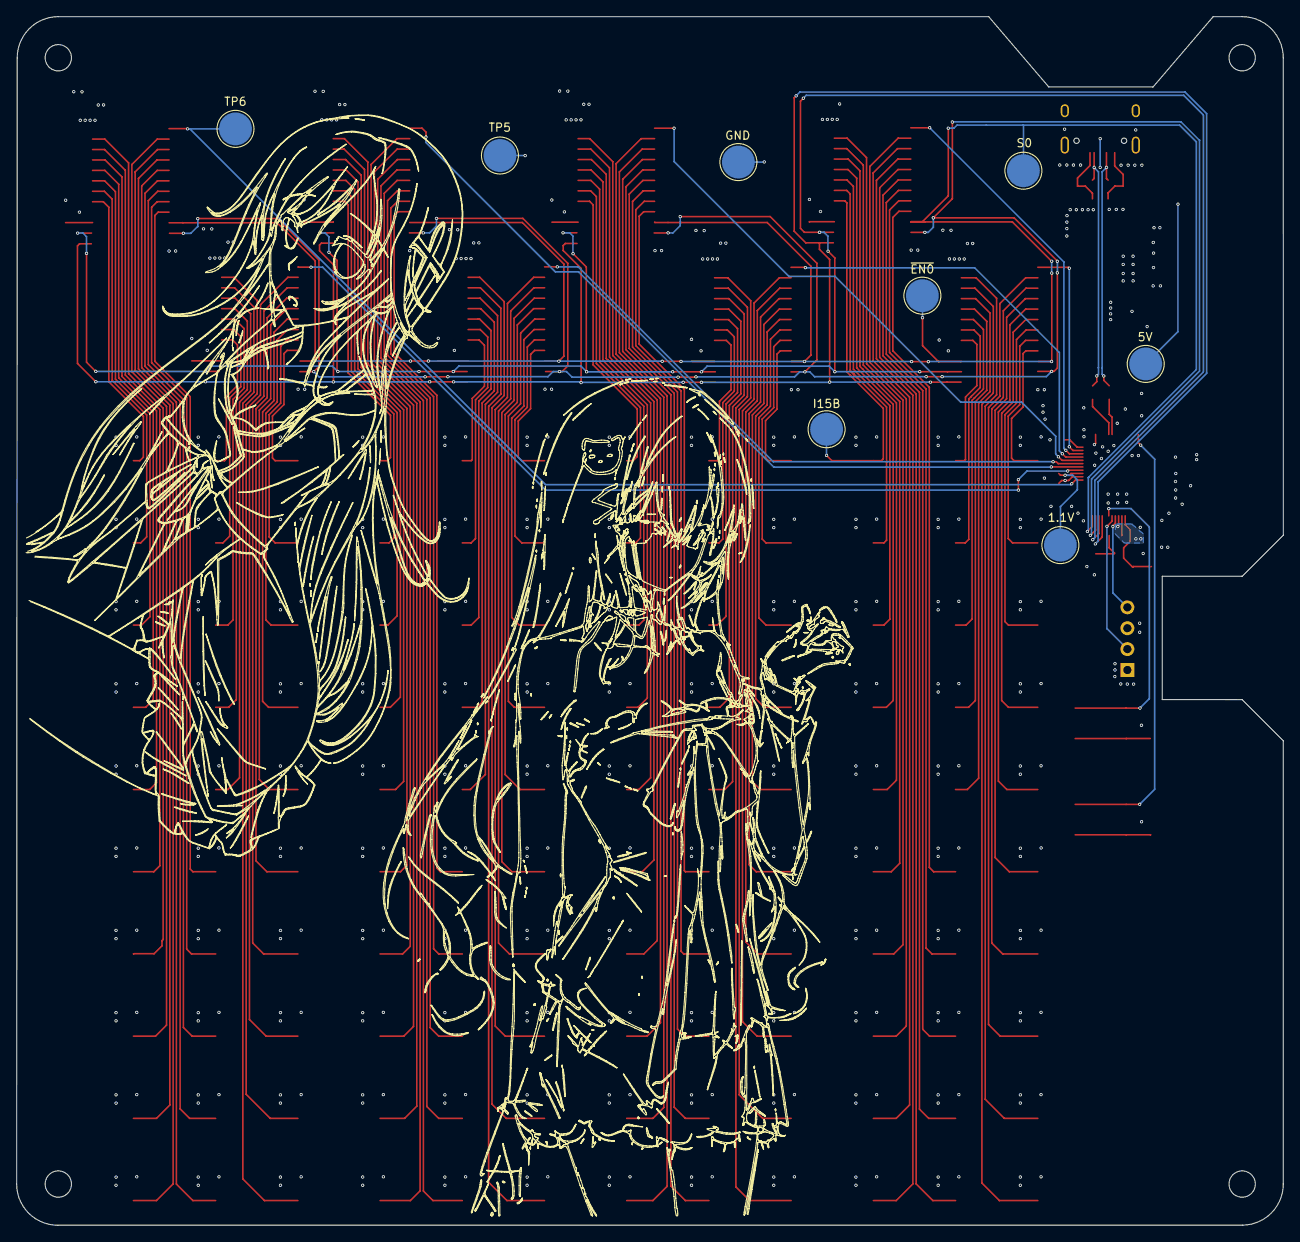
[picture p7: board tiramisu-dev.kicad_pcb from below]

Board: 4 copper layers, 154.1 x 147.0 mm, 324 parts (8 on the bottom side), 161 nets.

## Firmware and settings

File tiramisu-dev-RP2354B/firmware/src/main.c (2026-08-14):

// aim1k tablet — top level.
//
// core 1: free-running DMA scan of the 120-sensor hall grid (sensors.c).
// core 0: USB, localisation (solve.c), output filtering (filter.c), 1 kHz HID.
//
// The scan and the report loop are deliberately decoupled: core 1 publishes
// frames as fast as it can (~1.8 kHz) through a seqlock and core 0 always solves
// the freshest one, so report jitter never depends on scan timing.
#include <math.h>
#include <stdio.h>
#include "pico/stdlib.h"
#include "tusb.h"

#include "config.h"
#include "hid_report.h"
#include "sensors.h"
#include "solve.h"
#include "filter.h"

static one_euro_t s_filter;
static sensor_frame_t s_frame;
static pen_pos_t s_pos;
static uint16_t s_last_x = LOGICAL_MAX_X / 2, s_last_y = LOGICAL_MAX_Y / 2;
static bool s_was_in_range = false;
static absolute_time_t s_last_report;
static absolute_time_t s_last_solve;
static volatile bool s_mouse_on = (MOUSE_DEFAULT_ON != 0);
static bool s_send_mouse_next = false;
static bool s_idle_sent = false;

static inline uint16_t clamp_u16(float v, uint16_t hi) {
    if (v < 0) return 0;
    if (v > hi) return hi;
    return (uint16_t)(v + 0.5f);
}

#if DEBUG_CONSOLE
// Defined with the rest of the console, below; called from the report loop
// because that is the only place that sees every reported position.
static void dbg_jitter_sample(float raw_x, float raw_y, float flt_x, float flt_y);

// Solve time, so the 1 ms report budget can be checked on real hardware rather
// than estimated. The dipole fit is the only thing here that could plausibly
// overrun it, and the answer depends on the flash/XIP cache, not on arithmetic
// anyone can count. Reported by 'i'.
static uint32_t s_solve_us_max = 0, s_solve_us_acc = 0, s_solve_n = 0;
#endif

// Solve the freshest frame and queue exactly one report.
//
// This is called from tud_hid_report_complete_cb, i.e. once per report the host
// actually collected, so the cadence is phase-locked to the host's polling.
// The previous design ran a free-running 1 ms timer and skipped the report
// whenever tud_hid_ready() happened to be false at the deadline; because that
// timer and the USB SOF drift against each other, the skips came in a beat
// pattern and cost ~6% of frames (measured 945 Hz with 6% of intervals ~2 ms).
static void report_once(void) {
    if (!tud_hid_ready()) return;

    // Measured, not assumed. The chain is driven by the host's polling and by a
    // 2 ms watchdog, so the spacing is only nominally 1 ms, and every cutoff in
    // the output filter is derived from it.
    const absolute_time_t now = get_absolute_time();
    const float dt = (float)absolute_time_diff_us(s_last_solve, now) * 1e-6f;
    s_last_solve = now;

    if (sensors_get_latest(&s_frame)) {
#if DEBUG_CONSOLE
        const absolute_time_t t0 = get_absolute_time();
#endif
        solve_position(&s_frame, &s_pos);
#if DEBUG_CONSOLE
        const uint32_t us =
            (uint32_t)absolute_time_diff_us(t0, get_absolute_time());
        if (us > s_solve_us_max) s_solve_us_max = us;
        s_solve_us_acc += us;
        s_solve_n++;
#endif
        // Hand the pen's location back to the scanner. Baseline drift tracking
        // has to stop under a resting magnet, or it absorbs the very signal it
        // is the reference for — but only under it. Everywhere else has to keep
        // tracking, or drift accumulates there instead and eventually looks more
        // like a pen than the pen does.
        sensors_set_pen_cell(solve_pen_cell());
        if (s_pos.in_range != s_was_in_range) one_euro_reset(&s_filter);
        s_was_in_range = s_pos.in_range;
    }

    pen_report_t r = {0};
    if (s_pos.in_range) {
        // Hover-only by design: the tablet reports position, clicks come from the
        // keyboard (osu! K1/K2). The button bits are intentionally never set.
        float fx = s_pos.x_mm, fy = s_pos.y_mm;
#if FILTER_ENABLE
        one_euro_apply(&s_filter, s_pos.x_mm, s_pos.y_mm, dt, &fx, &fy);
#endif
#if DEBUG_CONSOLE
        dbg_jitter_sample(s_pos.x_mm, s_pos.y_mm, fx, fy);
#endif
        r.buttons  = PEN_IN_RANGE;
        r.x        = clamp_u16(fx / AREA_W_MM * LOGICAL_MAX_X, LOGICAL_MAX_X);
        r.y        = clamp_u16(fy / AREA_H_MM * LOGICAL_MAX_Y, LOGICAL_MAX_Y);
        r.pressure = 0;
        s_last_x = r.x;
        s_last_y = r.y;
    } else {
        r.buttons = 0;                            // pen lifted
        r.x = s_last_x;
        r.y = s_last_y;
    }

    // No pen: send one final "lifted" report, then go quiet until it comes back.
    //
    // A tablet that keeps streaming its last position pins the cursor there and
    // makes the regular mouse unusable - through the mouse collection directly,
    // and through OTD too, since its parser applies a position for every report
    // it receives. Real tablets stop reporting once the pen leaves proximity, so
    // this one does the same and the cursor is free for anything else to move.
    // s_last_report is still stamped so the main-loop watchdog keeps ticking at
    // its 2 ms pace instead of spinning.
    if (!s_pos.in_range) {
        s_last_report = get_absolute_time();
        if (s_idle_sent) return;
        s_idle_sent = true;
        tud_hid_report(REPORT_ID_PEN, &r, sizeof(r));
        return;
    }
    s_idle_sent = false;

    bool queued;
#if !VENDOR_ONLY
    // Alternate: the vendor report always goes out (OTD needs every sample), and
    // the mouse report only while the mouse collection is enabled. They alternate
    // rather than both going out per poll because one interrupt-IN transfer per
    // 1 ms frame is all USB Full-Speed allows - sending both would halve the rate
    // OTD sees. Standalone (no OTD) the mouse still gets a fresh 500 Hz, and with
    // OTD driving, the mouse collection is off and the pen gets the full 1 kHz.
    if (s_mouse_on && s_send_mouse_next) {
        mouse_report_t m = {0};
        m.buttons = 0;
        m.x = (uint16_t)((uint32_t)r.x * MOUSE_LOGICAL_MAX / LOGICAL_MAX_X);
        m.y = (uint16_t)((uint32_t)r.y * MOUSE_LOGICAL_MAX / LOGICAL_MAX_Y);
        queued = tud_hid_report(REPORT_ID_MOUSE, &m, sizeof(m));
    } else {
        queued = tud_hid_report(REPORT_ID_PEN, &r, sizeof(r));
    }
    s_send_mouse_next = !s_send_mouse_next;
#else
    queued = tud_hid_report(REPORT_ID_PEN, &r, sizeof(r));
#endif

    if (queued) s_last_report = get_absolute_time();
}

// Host-side mode switch. OTD sends this via FeatureInitReport in aim1k.json so
// Windows' own cursor motion stops the moment OTD takes over; without it the two
// would fight over the pointer.
uint16_t tud_hid_get_report_cb(uint8_t instance, uint8_t report_id,
                               hid_report_type_t report_type,
                               uint8_t *buffer, uint16_t reqlen) {
    (void)instance;
    if (report_type == HID_REPORT_TYPE_FEATURE &&
        report_id == REPORT_ID_MODE && reqlen >= 1) {
        buffer[0] = s_mouse_on ? 1 : 0;
        return 1;
    }
    return 0;
}

void tud_hid_set_report_cb(uint8_t instance, uint8_t report_id,
                           hid_report_type_t report_type,
                           uint8_t const *buffer, uint16_t bufsize) {
    (void)instance;
    if (report_type != HID_REPORT_TYPE_FEATURE || bufsize < 1) return;

    // Depending on the stack, the report ID may arrive in report_id or as the
    // first payload byte. Accept both rather than depend on which.
    uint8_t id = report_id;
    const uint8_t *p = buffer;
    uint16_t n = bufsize;
    if (id == 0) {
        id = buffer[0];
        p++;
        n--;
    }
    if (id == REPORT_ID_MODE && n >= 1) s_mouse_on = (p[0] != 0);
}

// Chain: every completed report immediately queues the next one.
void tud_hid_report_complete_cb(uint8_t instance, uint8_t const *report,
                                uint16_t len) {
    (void)instance; (void)report; (void)len;
    report_once();
}

// ---- Debug console ----------------------------------------------------------
// A CDC serial port that dumps the raw grid. This is the instrument the sensor
// map and the noise thresholds are verified against — see scripts/grid_view.py.
#if DEBUG_CONSOLE
static bool s_stream = false;
static char s_buf[1200];

static void dbg_banner(void) {
    int n = snprintf(s_buf, sizeof(s_buf),
        "\r\naim1k debug console\r\n"
        "  d = one deflection frame     r = one raw-count frame\r\n"
        "  n = per-sensor noise sigma   b = baseline\r\n"
        "  s = stream deflections       x = stop streaming\r\n"
        "  c = recalibrate (pen away!)  i = info\r\n"
        "  j = measure jitter (park the pen and keep still)\r\n"
        "  m = toggle mouse collection (off = let OTD drive)\r\n"
        "grid is %d cols x %d rows, row-major\r\n",
        SENSOR_COLS, SENSOR_ROWS);
    tud_cdc_write(s_buf, (uint32_t)n);
    tud_cdc_write_flush();
}

// Emit one tagged row-major array of 120 values.
static void dbg_dump(char tag, const float *v, bool as_int) {
    int n = snprintf(s_buf, sizeof(s_buf), "%c", tag);
    for (int i = 0; i < SENSOR_COUNT && n < (int)sizeof(s_buf) - 12; i++) {
        if (as_int)
            n += snprintf(s_buf + n, sizeof(s_buf) - n, " %d", (int)lrintf(v[i]));
        else
            n += snprintf(s_buf + n, sizeof(s_buf) - n, " %.2f", (double)v[i]);
    }
    n += snprintf(s_buf + n, sizeof(s_buf) - n, "\r\n");
    if (tud_cdc_write_available() >= (uint32_t)n) {
        tud_cdc_write(s_buf, (uint32_t)n);
        tud_cdc_write_flush();
    }
}

static void dbg_info(const pen_pos_t *p) {
    const float *sg = sensors_sigma();
    float smin = 1e30f, smax = 0.0f, ssum = 0.0f;
    for (int i = 0; i < SENSOR_COUNT; i++) {
        if (sg[i] < smin) smin = sg[i];
        if (sg[i] > smax) smax = sg[i];
        ssum += sg[i];
    }
    const double solve_avg = s_solve_n ? (double)s_solve_us_acc / s_solve_n : 0.0;
    const unsigned long solve_max = (unsigned long)s_solve_us_max;
    s_solve_us_max = 0; s_solve_us_acc = 0; s_solve_n = 0;   // max is since last 'i'

    int n = snprintf(s_buf, sizeof(s_buf),
        "scan %.0f Hz | sigma min %.2f mean %.2f max %.2f counts"
        " | solve %.0f us avg %lu us max (budget 1000)\r\n"
        "pen %s peak %.1f snr %.1f coh %.2f  x %.2f y %.2f z %.1f %s"
        " rms %.1f%s%s\r\n",
        (double)sensors_frame_rate(), (double)smin,
        (double)(ssum / SENSOR_COUNT), (double)smax, solve_avg, solve_max,
        p->in_range ? "IN " : "out", (double)p->peak, (double)p->snr,
        (double)p->coherence, (double)p->x_mm, (double)p->y_mm,
        (double)p->z_mm, p->refined ? "(dipole)" : "(centroid)",
        (double)p->fit_rms,
        p->outside ? " OFF-AREA" : "",
        (p->blob && !p->in_range) ? " (blob, untrusted)" : "");
    tud_cdc_write(s_buf, (uint32_t)n);
    tud_cdc_write_flush();
}

// ---- Jitter measurement -----------------------------------------------------
// Park the magnet, press 'j', don't touch anything. Reports the standard
// deviation and peak-to-peak of the reported position over the capture, both
// before and after the output filter, so "is it still glitching" has a number
// instead of an opinion. Peak-to-peak is the one that matters for the symptom:
// a discrete jump shows up there long before it moves the standard deviation.
typedef struct {
    uint32_t n;
    float mx, my, m2x, m2y;      // Welford
    float lo_x, hi_x, lo_y, hi_y;
} jitter_t;

static jitter_t s_jit_raw, s_jit_flt;
static uint32_t s_jit_left = 0;          // frames still to capture
static bool     s_jit_ready = false;

static void jit_reset(jitter_t *j) {
    j->n = 0;
    j->mx = j->my = j->m2x = j->m2y = 0.0f;
    j->lo_x = j->lo_y =  1e30f;
    j->hi_x = j->hi_y = -1e30f;
}

static void jit_push(jitter_t *j, float x, float y) {
    j->n++;
    const float dx = x - j->mx, dy = y - j->my;
    j->mx += dx / (float)j->n;
    j->my += dy / (float)j->n;
    j->m2x += dx * (x - j->mx);
    j->m2y += dy * (y - j->my);
    if (x < j->lo_x) j->lo_x = x;
    if (x > j->hi_x) j->hi_x = x;
    if (y < j->lo_y) j->lo_y = y;
    if (y > j->hi_y) j->hi_y = y;
}

static inline float jit_sd(float m2, uint32_t n) {
    return (n > 1) ? sqrtf(m2 / (float)(n - 1)) : 0.0f;
}

static void dbg_jitter_sample(float raw_x, float raw_y, float flt_x, float flt_y) {
    if (!s_jit_left) return;
    jit_push(&s_jit_raw, raw_x, raw_y);
    jit_push(&s_jit_flt, flt_x, flt_y);
    if (--s_jit_left == 0) s_jit_ready = true;
}

static void dbg_jitter_report(void) {
    if (s_jit_raw.n < 2) {
        tud_cdc_write_str("jitter: no in-range frames captured\r\n");
        tud_cdc_write_flush();
        return;
    }
    int n = snprintf(s_buf, sizeof(s_buf),
        "jitter over %lu frames (mm)\r\n"
        "  solver   sd %.4f %.4f  p2p %.3f %.3f\r\n"
        "  filtered sd %.4f %.4f  p2p %.3f %.3f\r\n",
        (unsigned long)s_jit_raw.n,
        (double)jit_sd(s_jit_raw.m2x, s_jit_raw.n),
        (double)jit_sd(s_jit_raw.m2y, s_jit_raw.n),
        (double)(s_jit_raw.hi_x - s_jit_raw.lo_x),
        (double)(s_jit_raw.hi_y - s_jit_raw.lo_y),
        (double)jit_sd(s_jit_flt.m2x, s_jit_flt.n),
        (double)jit_sd(s_jit_flt.m2y, s_jit_flt.n),
        (double)(s_jit_flt.hi_x - s_jit_flt.lo_x),
        (double)(s_jit_flt.hi_y - s_jit_flt.lo_y));
    tud_cdc_write(s_buf, (uint32_t)n);
    tud_cdc_write_flush();
}

static void dbg_poll(const sensor_frame_t *f, const pen_pos_t *p) {
    static bool was_connected = false;
    const bool now_connected = tud_cdc_connected();
    if (now_connected && !was_connected) dbg_banner();
    was_connected = now_connected;
    if (!now_connected) { s_stream = false; return; }

    while (tud_cdc_available()) {
        int ch = tud_cdc_read_char();
        switch (ch) {
        case 'd': dbg_dump('D', f->value, true); break;
        case 'n': dbg_dump('N', sensors_sigma(), false); break;
        case 'b': dbg_dump('B', sensors_baseline(), true); break;
        case 'r': {
            static float raw[SENSOR_COUNT];
            const float *bl = sensors_baseline();
            for (int i = 0; i < SENSOR_COUNT; i++) raw[i] = f->value[i] + bl[i];
            dbg_dump('R', raw, true);
            break;
        }
        case 's': s_stream = true;  break;
        case 'x': s_stream = false; break;
        case 'i': dbg_info(p); break;
        case 'j':
            jit_reset(&s_jit_raw);
            jit_reset(&s_jit_flt);
            s_jit_ready = false;
            s_jit_left  = JITTER_FRAMES;
            tud_cdc_write_str("measuring jitter, hold still...\r\n");
            tud_cdc_write_flush();
            break;
        case 'm':
            s_mouse_on = !s_mouse_on;
            tud_cdc_write_str(s_mouse_on
                ? "mouse collection ON (cursor moves with no driver)\r\n"
                : "mouse collection OFF (OpenTabletDriver drives the cursor)\r\n");
            tud_cdc_write_flush();
            break;
        case 'c':
            tud_cdc_write_str("recalibrating, keep the pen away...\r\n");
            tud_cdc_write_flush();
            sensors_request_recalibrate();
            solve_reset();
            one_euro_reset(&s_filter);
            break;
        default: break;
        }
    }

    if (s_jit_ready) {
        s_jit_ready = false;
        dbg_jitter_report();
    }

    if (s_stream) {
        static absolute_time_t next = {0};
        if (absolute_time_diff_us(get_absolute_time(), next) <= 0) {
            next = make_timeout_time_ms(1000 / DEBUG_STREAM_HZ);
            dbg_dump('D', f->value, true);
        }
    }
}
#endif // DEBUG_CONSOLE

int main(void) {
    sensors_init();
    tusb_init();
    one_euro_init(&s_filter, (float)REPORT_HZ,
                  FILTER_MIN_CUTOFF, FILTER_BETA, FILTER_DCUTOFF);

    // Let enumeration settle, then learn the no-magnet baseline AND the per-sensor
    // noise sigma. Keep the pen off the tablet for the first ~half second.
    absolute_time_t warmup = make_timeout_time_ms(500);
    while (!time_reached(warmup)) tud_task();
    sensors_calibrate(NOISE_CAL_FRAMES);

    // Hand the grid scan to core 1; core 0 now only does USB + solve + filter.
    sensors_start();

    s_last_report = get_absolute_time();
    s_last_solve  = s_last_report;

    for (;;) {
        tud_task();

        // The report chain is self-sustaining, but it has to be kick-started
        // after enumeration and restarted if it ever stalls (suspend/resume, a
        // refused queue). Anything past ~2 ms means the chain is not running.
        if (tud_hid_ready() &&
            absolute_time_diff_us(s_last_report, get_absolute_time()) > 2000)
            report_once();

#if DEBUG_CONSOLE
        dbg_poll(&s_frame, &s_pos);
#endif
    }
}

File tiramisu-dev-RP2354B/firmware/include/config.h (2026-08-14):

#pragma once
// aim1k tablet firmware — build-time configuration.

// ---- USB identity -----------------------------------------------------------
// 0x1209/0x0001 is the pid.codes prototype VID/PID. Register a real PID before
// distributing. The OpenTabletDriver config (opentabletdriver/aim1k.json) MUST
// match these two values.
#define USB_VID           0x1209
#define USB_PID           0x0001
#define USB_MANUFACTURER  "aim1k"
#define USB_PRODUCT       "aim1k tablet"

// ---- Active area ------------------------------------------------------------
// Sensor-centre span is 110 x 90 mm. We report absolute coordinates in units of
// 0.01 mm so OpenTabletDriver sees Width=110 mm, Height=90 mm cleanly.
#define AREA_W_MM         110.0f
#define AREA_H_MM         90.0f
#define LOGICAL_MAX_X     11000   // 110.00 mm
#define LOGICAL_MAX_Y     9000    // 90.00 mm
#define LOGICAL_MAX_P     4095    // pressure (stubbed; 12-bit)

// ---- Report cadence ---------------------------------------------------------
// 1000 Hz is the CEILING here, not a choice. USB Full-Speed has a 1 ms frame and
// bInterval=1 is the minimum, so one interrupt-IN transfer per millisecond is all
// the bus allows. Beating it needs High-Speed microframes (125 us), and the
// RP2350/RP2354B USB controller is Full-Speed only. Reports are driven from
// tud_hid_report_complete_cb (see main.c) so the cadence is locked to the host's
// actual polling instead of a free-running timer that beats against it.
#define REPORT_HZ         1000    // USB Full-Speed 1 ms interval
#define HID_POLL_MS       1

// ---- HID personality --------------------------------------------------------
// The device exposes TWO top-level collections on one interface:
//
//   REPORT_ID_MOUSE  absolute mouse  -> Windows moves the cursor with no driver,
//                                       mapped to the whole virtual desktop.
//   REPORT_ID_PEN    vendor-defined  -> OpenTabletDriver reads this one.
//
// Why two. A Digitizer/Pen descriptor drags in Windows Ink AND makes Windows
// open the collection EXCLUSIVELY, so OTD gets ACCESS_DENIED - that is a hard
// wall, not a config problem. A mouse collection gives driverless cursor control
// with no ink stack anywhere, but Windows claims it exclusively too. Windows
// claims collections individually, though, so the vendor collection next to it
// stays open for OTD. This is the same split commercial tablets ship.
//
// Only one may drive the cursor at a time or they fight, so mouse reports are
// switched off when OTD takes over, via a feature report on REPORT_ID_MODE
// (byte 0: 1 = mouse on, 0 = mouse off). OTD sends it through FeatureInitReport
// in aim1k.json; the CDC console 'm' command toggles it as a fallback.
#define MOUSE_DEFAULT_ON  1     // plug-and-play out of the box

// Set to 1 to drop the mouse collection entirely (vendor-only build).
#define VENDOR_ONLY       0

// ---- Acquisition ------------------------------------------------------------
// After changing the shared address bus, every mux COM line has to settle before
// the ADC front-end sees a valid level. Tune on a scope (bring-up step 3).
#define ADC_SETTLE_US     5

// The RP2350 has ONE ADC behind an 8-input front mux. Switching inputs at
// 500 kSa/s with the CD74HC4067's Ron (~200 ohm at 3V3) in series does not give
// the sample-and-hold cap time to fully charge, so each input is contaminated by
// the previous one — classic round-robin crosstalk, and a prime suspect for
// "the grid reads wrong". Run the round-robin TWICE per address and keep only
// the second pass: the first pass leaves each S&H already near its final value.
// Costs 16 us/address; a full frame is still ~555 us => ~1.8 kHz.
#define ADC_WARMUP_PASS   1

// Frames averaged per published frame. 1 is usually right now that the warm-up
// pass does the heavy lifting; raise it only if noise is still the limit.
#define OVERSAMPLE        1

// Sliding boxcar over the last N PUBLISHED frames. This is nearly free noise
// reduction: core 1 scans at ~1.8 kHz but core 0 only consumes at 1 kHz, so
// ~45% of frames were being computed and then discarded. Averaging N of them
// divides the noise by sqrt(N) and costs only (N-1)/2 frame times of latency
// (~0.28 ms at N=2), because the window SLIDES — every scan still publishes.
// Raising OVERSAMPLE instead would buy the same sqrt(N) but at N times the
// frame period, which is real latency. Prefer this. 1 disables it.
#define FRAME_AVG         2
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

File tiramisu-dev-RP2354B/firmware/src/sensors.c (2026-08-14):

// Hall-grid acquisition for the aim1k tablet — DMA round-robin on core 1.
//
// Architecture (see ../docs/CALCULATIONS.md §2):
//   * S0..S3 form a shared 4-bit address bus to all eight muxes.
//   * All eight mux enables are tied low in hardware -> always active.
//   * The eight mux COM outputs land on GPIO40..47 (ADC inputs 0..7). The
//     schematic net names are reversed (net "ADC0" is on GPIO47 = ADC input 7),
//     but SENSOR_GRID is generated indexed BY ADC INPUT, so that is already
//     accounted for and the scan needs no reversal step of its own.
//   * The RP2350 has ONE ADC behind an 8-input front mux. In round-robin mode it
//     cycles inputs 0..7 back-to-back; a DMA channel drains those samples per
//     address straight into a buffer, so the CPU never polls the ADC.
//
// Written against the Raspberry Pi Pico SDK (RP2350).
#include "sensors.h"
#include "config.h"
#include "pico/stdlib.h"
#include "pico/multicore.h"
#include "hardware/adc.h"
#include "hardware/dma.h"
#include "hardware/gpio.h"
#include "hardware/sync.h"
#include <math.h>

#if ADC_WARMUP_PASS
  #define PASSES_PER_ADDR 2
#else
  #define PASSES_PER_ADDR 1
#endif
#define SAMPLES_PER_ADDR (MUX_COUNT * PASSES_PER_ADDR)

static int      s_dma = -1;
static uint16_t s_raw[SAMPLES_PER_ADDR];         // DMA target, one address
static float    s_baseline[SENSOR_COUNT];
static float    s_sigma[SENSOR_COUNT];
static bool     s_calibrated = false;
static volatile bool s_recal_req = false;
// Linear grid index of the pen, or -1 for none. Written by core 0, read by core
// 1; a single aligned 32-bit word, so it cannot tear and needs no lock.
static volatile int32_t s_pen_cell = -1;
static volatile float s_frame_hz = 0.0f;

#if FRAME_AVG > 1
// Sliding boxcar over the last FRAME_AVG raw frames. Held as a running sum plus
// the ring of terms in it, so each new frame costs one add and one subtract per
// sensor instead of re-summing the window.
static float    s_hist[FRAME_AVG][SENSOR_COUNT];
static float    s_hsum[SENSOR_COUNT];
static uint32_t s_hcount = 0;                    // frames pushed, saturating
static uint32_t s_hhead  = 0;
#endif

// Lock-free single-producer (core 1) / single-consumer (core 0) publish.
static volatile uint32_t g_seq = 0;              // odd = write in progress
static sensor_frame_t    g_shared;

static inline void set_address(uint8_t addr) {
    gpio_put(PIN_SEL_S0, (addr >> 0) & 1);
    gpio_put(PIN_SEL_S1, (addr >> 1) & 1);
    gpio_put(PIN_SEL_S2, (addr >> 2) & 1);
    gpio_put(PIN_SEL_S3, (addr >> 3) & 1);
    // Analog line settle after switching all eight muxes.
    busy_wait_us(ADC_SETTLE_US);
}

// Capture the eight ADC inputs at the currently-selected address via DMA.
// With ADC_WARMUP_PASS the round-robin runs twice and only the second pass is
// kept, so each input's sample-and-hold starts from (almost) the right level
// instead of from whatever the previous channel left behind.
static void capture_address(uint8_t addr, uint16_t *dst8) {
    set_address(addr);

    adc_run(false);
    adc_fifo_drain();
    adc_select_input(0);       // round-robin proceeds 0,1,...,7 from here

    dma_channel_config c = dma_channel_get_default_config(s_dma);
    channel_config_set_transfer_data_size(&c, DMA_SIZE_16);
    channel_config_set_read_increment(&c, false);
    channel_config_set_write_increment(&c, true);
    channel_config_set_dreq(&c, DREQ_ADC);
    dma_channel_configure(s_dma, &c, s_raw, &adc_hw->fifo,
                          SAMPLES_PER_ADDR, true);

    adc_run(true);
    dma_channel_wait_for_finish_blocking(s_dma);
    adc_run(false);

    // Keep the last pass.
    const uint16_t *keep = &s_raw[SAMPLES_PER_ADDR - MUX_COUNT];
    for (int i = 0; i < MUX_COUNT; i++) dst8[i] = keep[i];
}

#if FRAME_AVG > 1
static void frame_avg_reset(void) {
    s_hcount = 0;
    s_hhead  = 0;
    for (int i = 0; i < SENSOR_COUNT; i++) s_hsum[i] = 0.0f;
}

// Push one raw frame into the sliding window and replace it with the window
// mean. Running sum, so this is one add and one subtract per sensor rather than
// a re-sum of the whole window.
static void frame_avg_push(float f[SENSOR_COUNT]) {
    const bool full = (s_hcount >= FRAME_AVG);
    for (int i = 0; i < SENSOR_COUNT; i++) {
        if (full) s_hsum[i] -= s_hist[s_hhead][i];
        s_hist[s_hhead][i] = f[i];
        s_hsum[i] += f[i];
    }
    s_hhead = (s_hhead + 1u) % FRAME_AVG;
    if (!full) s_hcount++;
    const float inv = 1.0f / (float)(full ? (uint32_t)FRAME_AVG : s_hcount);
    for (int i = 0; i < SENSOR_COUNT; i++) f[i] = s_hsum[i] * inv;
}
#endif

// One full 120-sensor frame in raw ADC counts, de-interleaved into grid order.
static void raw_frame(float counts[SENSOR_COUNT]) {
    uint16_t addr_samples[MUX_COUNT];
    for (uint8_t addr = 0; addr < MUX_USED_CH; addr++) {
        capture_address(addr, addr_samples);
        for (int in = 0; in < MUX_COUNT; in++) {
            uint16_t idx = SENSOR_GRID[in][addr];
            if (idx != 0xFFFF)
                counts[idx] = (float)(addr_samples[in] & 0x0FFF);
        }
    }
}

void sensors_init(void) {
    const uint sel[4] = { PIN_SEL_S0, PIN_SEL_S1, PIN_SEL_S2, PIN_SEL_S3 };
    for (int i = 0; i < 4; i++) {
        gpio_init(sel[i]);
        gpio_set_dir(sel[i], GPIO_OUT);
        gpio_put(sel[i], 0);
    }

    adc_init();
    for (int i = 0; i < MUX_COUNT; i++)
        adc_gpio_init(ADC_GPIO_BASE + i);          // GPIO40..47
    adc_set_round_robin((1u << MUX_COUNT) - 1);    // inputs 0..7
    adc_fifo_setup(true,  // enable FIFO
                   true,  // DREQ enable (paces the DMA)
                   1,     // DREQ threshold: 1 sample
                   false, // no error bit in FIFO
                   false);// 16-bit samples (no byte shift)
    adc_set_clkdiv(0);                             // back-to-back, ~2 us/sample

    s_dma = dma_claim_unused_channel(true);

    for (int i = 0; i < SENSOR_COUNT; i++) s_sigma[i] = SIGMA_FLOOR;
}

// Welford: one pass gives both the mean (baseline) and the variance (noise sigma
// that every threshold downstream is expressed in).
void sensors_calibrate(uint32_t frames) {
    if (frames < 2) frames = 2;

    // Static, not stack: core 1's default stack is 2 KB and this runs there on a
    // recalibrate request, nested inside scan_core1's own scratch buffers.
    static float mean[SENSOR_COUNT];
    static float m2[SENSOR_COUNT];
    static float f[SENSOR_COUNT];

    for (int i = 0; i < SENSOR_COUNT; i++) { mean[i] = 0.0f; m2[i] = 0.0f; }
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

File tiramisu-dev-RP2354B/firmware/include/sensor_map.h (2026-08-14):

// AUTO-GENERATED by scripts/gen_sensor_map.py from tiramisu-dev.kicad_pcb
// - do not edit by hand. Re-run it whenever the PCB changes.
// 120 x HAL403SO, 12 cols x 10 rows, 10.0 mm pitch.
#pragma once
#include <stdint.h>

#define SENSOR_COLS   12
#define SENSOR_ROWS   10
#define SENSOR_COUNT  120
#define SENSOR_PITCH_MM   10.0f
#define MUX_COUNT     8
#define MUX_CHANNELS  16
#define MUX_USED_CH   15   // channel 15 is tied to GND on every mux

// Mux select lines (shared bus). Enables are tied low in hardware.
#define PIN_SEL_S0  32
#define PIN_SEL_S1  31
#define PIN_SEL_S2  30
#define PIN_SEL_S3  29
#define ADC_GPIO_BASE 40  // ADC input i -> GPIO(40+i)

// grid[adc_input][channel] -> linear sensor index (row*COLS+col),
// 0xFFFF = unused. Indexed by ADC INPUT, so the scanner needs no
// reversal step: the net names ADC0..ADC7 are wired backwards, and
// that is already accounted for here.
static const uint16_t SENSOR_GRID[MUX_COUNT][MUX_CHANNELS] = {
  { 0x0046, 0x0052, 0x005E, 0x006A, 0x0076, 0x0077, 0x006B, 0x005F, 0x0053, 0x0047, 0x003B, 0x002F, 0x0023, 0x0017, 0x000B, 0xFFFF }, // ADC in 0 = GPIO40, U9 (net ADC7)
  { 0x0009, 0x0015, 0x0021, 0x002D, 0x0039, 0x0045, 0x0051, 0x005D, 0x0069, 0x0075, 0x003A, 0x002E, 0x0022, 0x0016, 0x000A, 0xFFFF }, // ADC in 1 = GPIO41, U6 (net ADC6)
  { 0x0043, 0x004F, 0x005B, 0x0067, 0x0073, 0x0074, 0x0068, 0x005C, 0x0050, 0x0044, 0x0038, 0x002C, 0x0020, 0x0014, 0x0008, 0xFFFF }, // ADC in 2 = GPIO42, U3 (net ADC5)
  { 0x0006, 0x0012, 0x001E, 0x002A, 0x0036, 0x0042, 0x004E, 0x005A, 0x0066, 0x0072, 0x0037, 0x002B, 0x001F, 0x0013, 0x0007, 0xFFFF }, // ADC in 3 = GPIO43, U8 (net ADC4)
  { 0x0040, 0x004C, 0x0058, 0x0064, 0x0070, 0x0071, 0x0065, 0x0059, 0x004D, 0x0041, 0x0035, 0x0029, 0x001D, 0x0011, 0x0005, 0xFFFF }, // ADC in 4 = GPIO44, U5 (net ADC3)
  { 0x0003, 0x000F, 0x001B, 0x0027, 0x0033, 0x003F, 0x004B, 0x0057, 0x0063, 0x006F, 0x0034, 0x0028, 0x001C, 0x0010, 0x0004, 0xFFFF }, // ADC in 5 = GPIO45, U2 (net ADC2)
  { 0x003D, 0x0049, 0x0055, 0x0061, 0x006D, 0x006E, 0x0062, 0x0056, 0x004A, 0x003E, 0x0032, 0x0026, 0x001A, 0x000E, 0x0002, 0xFFFF }, // ADC in 6 = GPIO46, U7 (net ADC1)
  { 0x0000, 0x000C, 0x0018, 0x0024, 0x0030, 0x003C, 0x0048, 0x0054, 0x0060, 0x006C, 0x0031, 0x0025, 0x0019, 0x000D, 0x0001, 0xFFFF }, // ADC in 7 = GPIO47, U4 (net ADC0)
};

static inline float sensor_x_mm(int idx){ return (idx % SENSOR_COLS) * SENSOR_PITCH_MM; }
static inline float sensor_y_mm(int idx){ return (idx / SENSOR_COLS) * SENSOR_PITCH_MM; }

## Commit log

2026-08-14 Updated with aim-1k repo
    [20mm-pen2-v0.stl, Untitled.gcode.3mf, Untitled2.gcode.3mf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]
2026-08-14 Flag the pen-down signal figure as a suspected ADC rail
    Bring-up was done by sliding a bare 6mm x 10mm magnet directly on the
    tablet surface rather than with a pen. CALCULATIONS.md section 4 puts
    that at ~343 mT, far outside a linear Hall's range, and 4095 - 2048 =
    2047 against the recorded "~2066 counts" - so the headline signal figure
    is very likely a clipped reading rather than a measurement.
    If so it also explains the ~14 mm working height: a saturated peak is
    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
2026-09-03 Replace the signal figures with measured values
    The previous commit called the ~2066 count figure a suspected ADC rail on
    the arithmetic 4095 - 2048 = 2047. Measured on hardware today: with the
    magnet flat on the surface the raw maximum is 2930 against a 4095 full
    scale, so there are 1165 counts of ADC headroom and nothing is clipping
    digitally. That claim was wrong.
    What is happening is compression in the HAL403 itself. CALCULATIONS.md
    section 4 puts the field at surface contact near 274 mT against ~20.5 mT
    for a magnet in a pen at ~10 mm - a 13x ratio - while the measured peaks
    are 936 and 406 counts, a 2.3x ratio. The near reading is compressed
    roughly 5x. Working back from the far point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
2026-11-05 prod kicad project
2026-11-06 vbus protection and filter
